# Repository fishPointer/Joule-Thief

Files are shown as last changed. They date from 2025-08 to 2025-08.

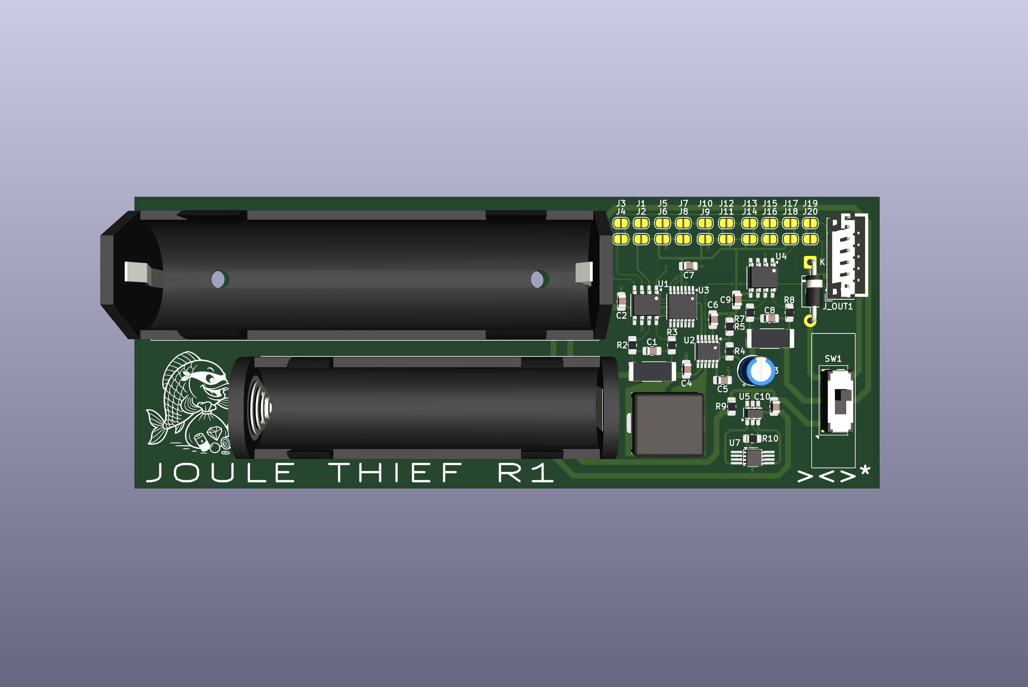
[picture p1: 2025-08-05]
KiCAD/Joule Thief/Renders/Joule Thief 3D Render.png

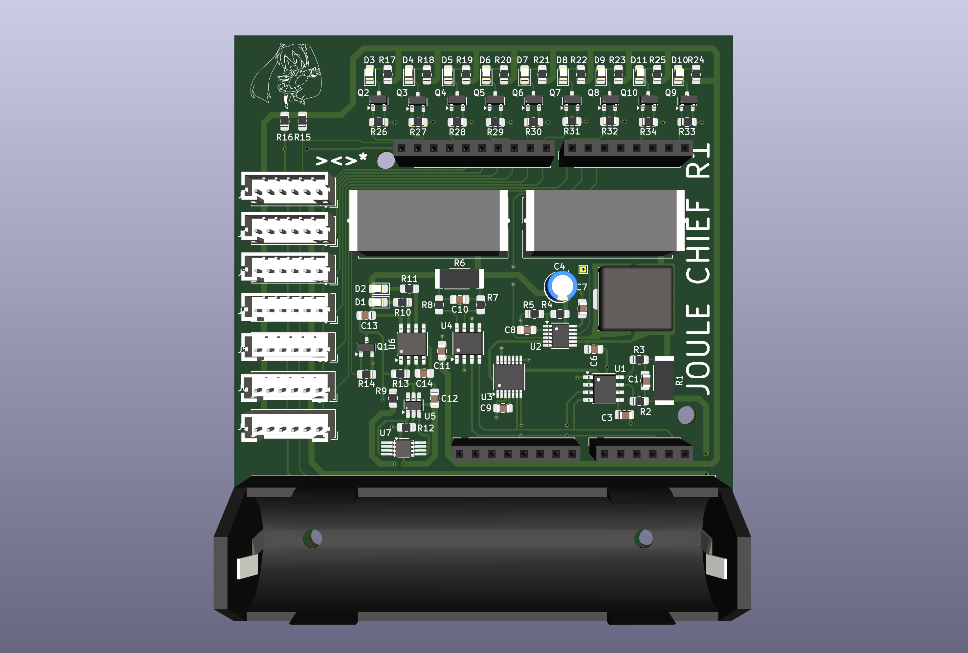
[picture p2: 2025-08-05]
KiCAD/Joule Chief/Renders/Joule Chief 3D Render.png

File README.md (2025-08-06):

Pasted image 20250805165937

# Joule Thief

## Overview
- **Purpose:** Exhibition project at Open Sauce July 18-20, 2025, Practice
- **Description:** High efficiency alkaline battery draining system with diagnostics and energy storage
- **Domain:** Precision energy harvesting & instrumentation

**Objectives:**
- Extract all usable electrical energy from used/"dead" Alkaline Cells (AA, AAA, etc.)
- Measure & Log energy extraction data from each cell & deliver analytics
- Efficiently convert and push energy extracted into a Li-Ion power bank

**Topology**
- **INA219** - Energy Metering
- **LTC3105** - Low Voltage Boost Converter
- **AD5280** - Digital Potentiometer, 200kΩ
- **DW01** - 18650 Single-cell BMS
- **TP4056** - Single-cell 18650 Charger
- **FS8205** - Dual-FET package for DW01
- **AO3400** - Low Voltage N-E-FET
- **1N5817** - Low Voltage Schottky Diode

**Status:** Complete. Exhibited. Working on Finalizing Documentation.

**Additional Documentation:** available on my Obsidian at [suneaterlabs.com](https://suneaterlabs.com).

**Why Joule Thief?**
This project was started as a New Year's Resolution to exhibit at Open Sauce 2025, and was finished 2 days prior to the event.
I have no commercial intent with this project. I don't believe that it is particularly novel, and a close look by anyone experienced with energy harvesting & power electronics should rightly reveal it as something akin to a useless machine.

I teach myself new skills by designing projects that require to develop the skills I want in order to complete them. I put a high level of effort into this project because I wanted to go through the process of designing a relatively performant embedded system without referencing anyone else's work. Just pick functionalities and features, set a spec, and then flip through datasheets until you find the right combination. Then put it all together and prove that it works. Design the schematic, route a board, write the firmware, etc. and then package it all up and provide thorough documentation on the whole thing.

I had never done any of that before and I have no professional experience working as an electronics engineer. I do have an EE degree and currently work in power system analysis for hyperscale datacenters, so this project is actually something like a microcosm of my day job. There is little overlap though, and I consider myself self-taught here. I learned a lot!

## System Description

### Joule Thief - Core Functionality
Joule Thief Schematic
The Joule Thief is designed to fully deplete alkaline cells of any remaining energy, long after they will fail to turn on their devices. The core of this design is the LTC3105, which can handle input voltages as low as 250mV. A quick look at an alkaline cell's SOC-OCV curve will show that draining to 300mV is sufficient to say >99% of total energy has been drained.

The classic Joule Thief is a simple party trick involving a dead battery, a hand-wound toroid, and a BJT. It is essentially using the voltage spike from inductive kickback to PWM an LED back to life. My motivation for this project was to demonstrate that there is a considerable amount of energy left in alkaline cells when they are discarded, so I set out to build an overengineered energy harvester that could precisely quantify how much energy was actually left in a dead cell, and then store it into a lithium-based battery bank to further prove the point.

 In order to improve performance and maximize both energy throughput and conversion efficiency, there is an INA219 shunt meter on either side of the LTC3105 boost chip allowing for efficiency tracking during processing & live diagnostics. 
 Additionally, the LTC3105 includes an MPPC pin, which enables a variable resistance to throttle the inductor's switching in order to achieve a specified input voltage. With the addition of an AD5280-200kΩ digital potentiometer attached to the MPPC pin, it is possible to read in energy measurements from the INA219's into a microcontroller, and then adjust the setting of the LTC3105 accordingly. The result is a control loop that can maximize the energy extraction rate regardless of the target cell's health or state of charge. 
 
 This INA219+LTC3105+AD5280 system can be tuned for maximum efficiency or maximum average power extracted, but optimizing for energy throughput has far greater performance gains. Using a DC Electronic Load to produce a slow sweep of load resistance values across a fresh AA alkaline cell will result in no more than 400-500mW peak extraction rate, and chemical effects such as electrolyte gradient formation and ion depletion make this power output unstable and liable to rapidly decline. The dynamic approach explored in the Joule Thief is able to achieve 900-1100mW peak output power, and can reliably maintain 600-700mW extraction rate in the early life of a cell. Additionally, the MPPC schema prevents the cell's output capacity from being overwhelmed by the battery chemistry effects, and the cell will continuously output higher power than traditional Joule Thief circuits or static loads.

The Joule Thief Extraction Module is also designed to run in "headless" mode without an MCU. No diagnostics are available in this mode (obviously) and the board will be able to move the energy from a single AA cell into a single 18650 cell safely.

### Joule Chief - Core Functionality
Joule Chief Schematic
The Joule Chief was designed to be a mainboard that allows for the consolidation of harvested energy from an arbitrary number of Joule Thief Extraction Modules collecting energy from different sources at different rates. The Joule Chief serves as both an aggregator and an abstraction layer for the energy harvested. 

The Joule Chief begins with a low-voltage schottky diode on the output of the extraction module to prevent backflow. After the energy is delivered to the mainboard's input bus, all the energy is stored in a 1F supercapacitor. The Joule Thief Extraction Modules are all set to boost whatever energy source they are targeting to 5V and charge the 1F supercap to 5V accordingly. 

Readings from the mainboard's INA219 allow the MCU to precisely track the voltage of the supercap as well as the power flowing into this buffer. The MCU is programmed to operate a schmitt trigger with thresholds at 2.5V and 5V, only enabling the 1F supercap's energy to pass through the mainboard's LTC3105 after 5V has been reached, and until 2.5V. This region of input voltage allows the boost chip to operate in a high-efficiency mode.

Once the energy has moved through the 1F supercap and through the LTC3105, it is stored in a second 1F supercap connected to the lithium cell charger. The cell charger is controlled by a second schmitt trigger running on the MCU as well. This schmitt trigger keeps the second 1F energy buffer between 4.5V and 5.0V, such that the buffer will always be an appropriate voltage for charging a lithium cell (3.0V to 4.3V).

The Joule Chief can handle an arbitrary number of extraction modules each working on arbitrarily weak or intermittent energy sources. This mainboard can effectively accumulate these energy sources and efficiently deposit this energy via intermittent pulses of energy into a rechargeable battery bank for later use while providing precise diagnostics at every stage of the harvesting process. The frequency of these charging pulses is dependent on the strength of the sources. Harvesting a sufficiently powerful source, such as a fresh AA cell, will allow the mainboard to achieve steady-state operation, and a continuous current flow into the 18650 becomes possible.

Both the Joule Thief and Joule Chief boards currently use a generic and inefficient BMS stack consisting of a DW01 for OC/OCD/SC protection, an FS8205 dual-FET package for breaking the circuit, and a TP4056 charging IC. This BMS is largely unnecessary given the low-power nature of this application, but was included for safety and peace of mind.

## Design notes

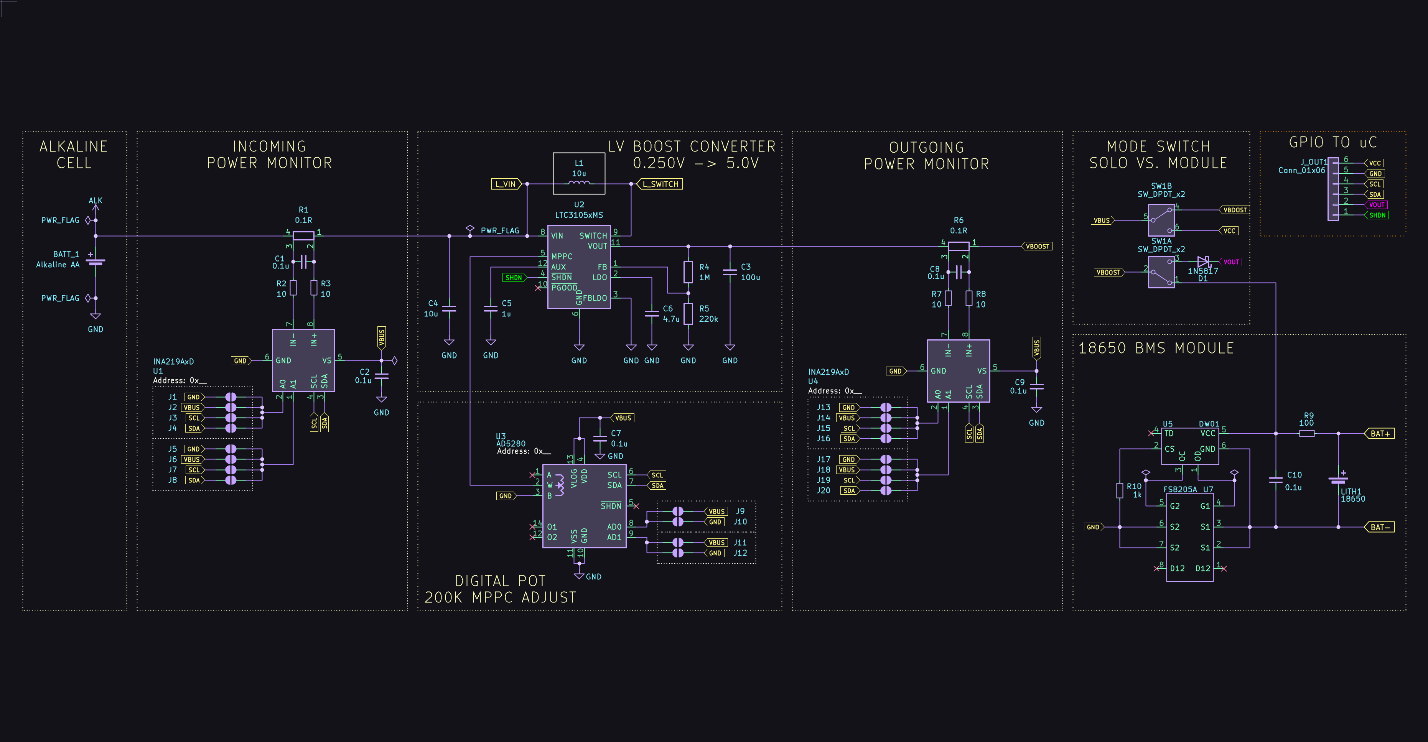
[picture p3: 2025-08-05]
KiCAD/Joule Thief/Renders/Joule Thief Schematic.png

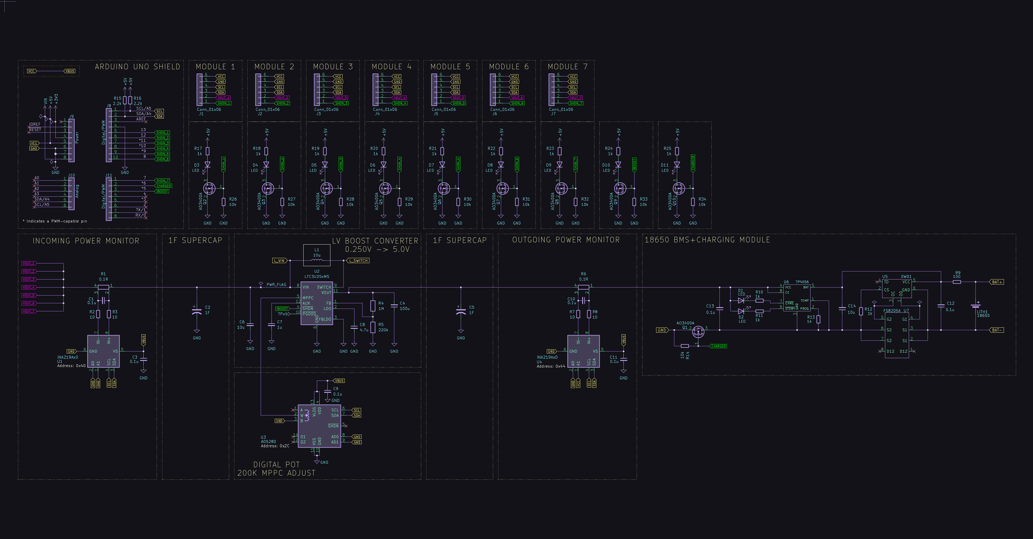
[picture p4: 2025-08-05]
KiCAD/Joule Chief/Renders/Joule Chief Schematic.png

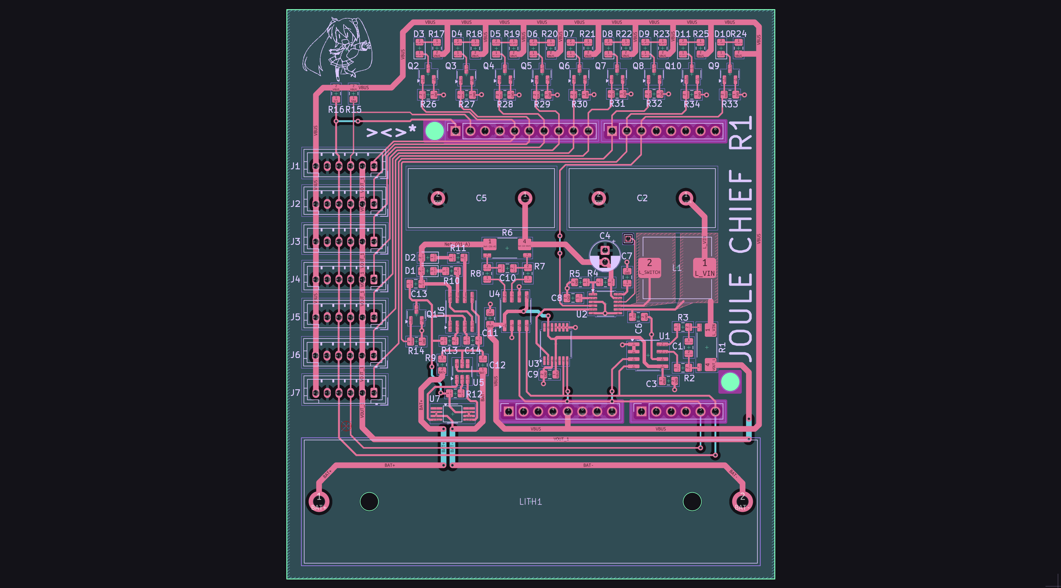
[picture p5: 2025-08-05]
KiCAD/Joule Chief/Renders/Joule Chief Layout.png

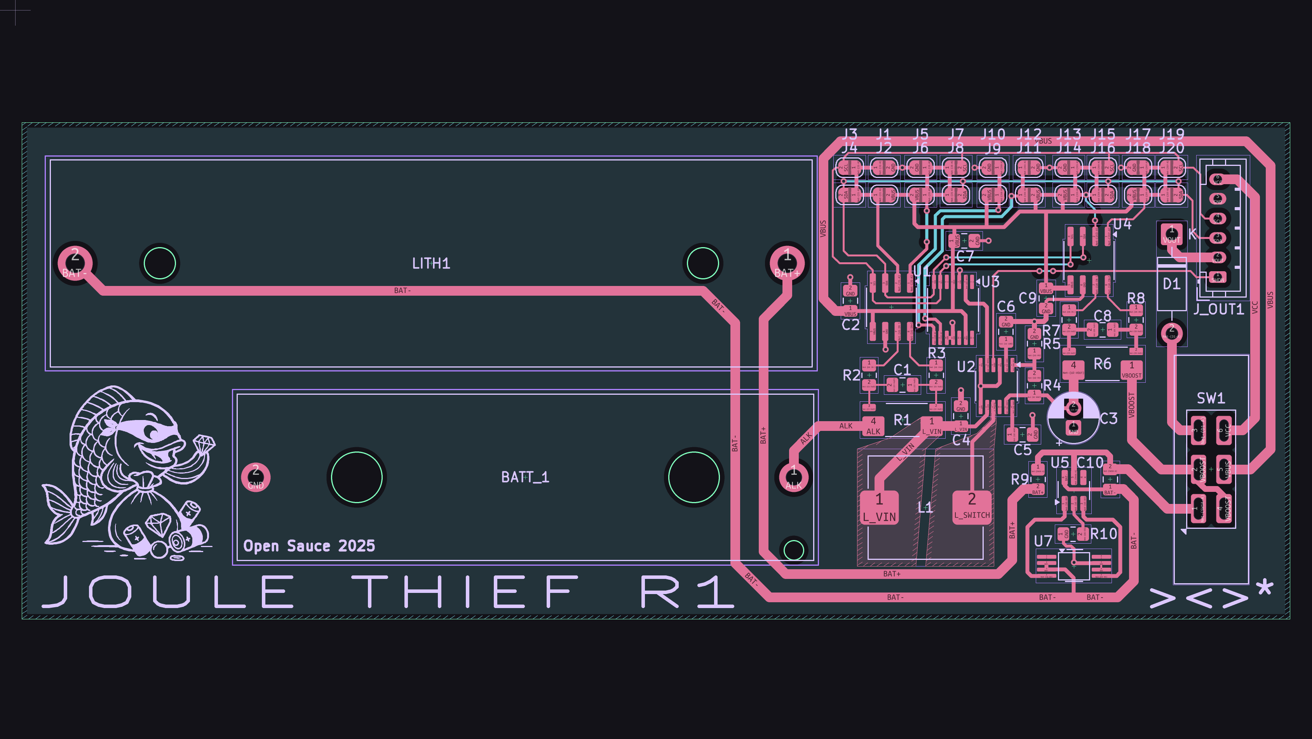
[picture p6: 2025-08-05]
KiCAD/Joule Thief/Renders/Joule Thief Layout.png

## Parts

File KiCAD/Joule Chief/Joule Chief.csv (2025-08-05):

Reference | Value | Qty | Footprint
C1,C3,C9,C10,C11,C12,C13 | 0.1u | 7 | Capacitor_SMD:C_0805_2012Metric_Pad1.18x1.45mm_HandSolder
C2,C5 | 1F | 2 | Joule Thief Footprints:1F_Supercap
C4 | 100u | 1 | Capacitor_THT:CP_Radial_D5.0mm_P2.00mm
C6,C14 | 10u | 2 | Capacitor_SMD:C_0805_2012Metric_Pad1.18x1.45mm_HandSolder
C7 | 1u | 1 | Capacitor_SMD:C_0805_2012Metric_Pad1.18x1.45mm_HandSolder
C8 | 4.7u | 1 | Capacitor_SMD:C_0805_2012Metric_Pad1.18x1.45mm_HandSolder
D1,D2,D3,D4,D5,D6,D7,D8,D9,D10,D11 | LED | 11 | LED_SMD:LED_0805_2012Metric_Pad1.15x1.40mm_HandSolder
J1,J2,J3,J4,J5,J6,J7 | Conn_01x06 | 7 | Connector_JST:JST_PH_B6B-PH-K_1x06_P2.00mm_Vertical
J8,J11 | Digital/PWM | 2 | Connector_PinSocket_2.54mm:PinSocket_1x08_P2.54mm_Vertical,Connector_PinSocket_2.54mm:PinSocket_1x10_P2.54mm_Vertical
J9 | Power | 1 | Connector_PinSocket_2.54mm:PinSocket_1x08_P2.54mm_Vertical
J10 | Analog | 1 | Connector_PinSocket_2.54mm:PinSocket_1x06_P2.54mm_Vertical
L1 | 10u | 1 | Joule Thief Footprints:Power_Inductor_101040
LITH1 | 18650 | 1 | Joule Thief Footprints:18650_Cell_Clip_V2
Q1,Q2,Q3,Q4,Q5,Q6,Q7,Q8,Q9,Q10 | AO3400A | 10 | Package_TO_SOT_SMD:SOT-23
R1,R6 | 0.1R | 2 | Joule Thief Footprints:R_Shunt_2512_V2
R2,R3,R7,R8 | 10 | 4 | Resistor_SMD:R_0805_2012Metric_Pad1.20x1.40mm_HandSolder
R4 | 1M | 1 | Resistor_SMD:R_0805_2012Metric_Pad1.20x1.40mm_HandSolder
R5 | 220k | 1 | Resistor_SMD:R_0805_2012Metric_Pad1.20x1.40mm_HandSolder
R9 | 100 | 1 | Resistor_SMD:R_0805_2012Metric_Pad1.20x1.40mm_HandSolder
R10,R11,R12,R13,R17,R18,R19,R20,R21,R22,R23,R24,R25 | 1k | 13 | Resistor_SMD:R_0805_2012Metric_Pad1.20x1.40mm_HandSolder
R14,R26,R27,R28,R29,R30,R31,R32,R33,R34 | 10k | 10 | Resistor_SMD:R_0805_2012Metric_Pad1.20x1.40mm_HandSolder
R15,R16 | 2.2k | 2 | Resistor_SMD:R_0805_2012Metric_Pad1.20x1.40mm_HandSolder
TPx1 | TestPoint_Alt | 1 | TestPoint:TestPoint_THTPad_1.0x1.0mm_Drill0.5mm
U1,U4 | INA219AxD | 2 | Package_SO:SOIC-8_3.9x4.9mm_P1.27mm
U2 | LTC3105xMS | 1 | Package_SO:MSOP-12_3x4.039mm_P0.65mm
U3 | AD5280 | 1 | Package_SO:TSSOP-14_4.4x5mm_P0.65mm
U5 | DW01 | 1 | Package_TO_SOT_SMD:SOT-23-6_Handsoldering
U6 | TP4056 | 1 | Package_SO:SOIC-8-1EP_3.9x4.9mm_P1.27mm_EP2.29x3mm
U7 | FS8205A | 1 | Joule Thief Footprints:FS8205A_Wide

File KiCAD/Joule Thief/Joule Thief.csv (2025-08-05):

Reference | Value | Qty | Footprint
BATT_1 | Alkaline AA | 1 | Joule Thief Footprints:AA_Cell_Clip_V2
C1,C2,C7,C8,C9,C10 | 0.1u | 6 | Capacitor_SMD:C_0805_2012Metric_Pad1.18x1.45mm_HandSolder
C3 | 100u | 1 | Capacitor_THT:CP_Radial_D5.0mm_P2.00mm
C4 | 10u | 1 | Capacitor_SMD:C_0805_2012Metric_Pad1.18x1.45mm_HandSolder
C5 | 1u | 1 | Capacitor_SMD:C_0805_2012Metric_Pad1.18x1.45mm_HandSolder
C6 | 4.7u | 1 | Capacitor_SMD:C_0805_2012Metric_Pad1.18x1.45mm_HandSolder
D1 | 1N5817 | 1 | Diode_THT:D_DO-41_SOD81_P10.16mm_Horizontal
J_OUT1 | Conn_01x06 | 1 | Connector_JST:JST_PH_B6B-PH-K_1x06_P2.00mm_Vertical
L1 | 10u | 1 | Joule Thief Footprints:Power_Inductor_101040
LITH1 | 18650 | 1 | Joule Thief Footprints:18650_Cell_Clip_V2
R1,R6 | 0.1R | 2 | Joule Thief Footprints:R_Shunt_2512_V2
R2,R3,R7,R8 | 10 | 4 | Resistor_SMD:R_0805_2012Metric_Pad1.20x1.40mm_HandSolder
R4 | 1M | 1 | Resistor_SMD:R_0805_2012Metric_Pad1.20x1.40mm_HandSolder
R5 | 220k | 1 | Resistor_SMD:R_0805_2012Metric_Pad1.20x1.40mm_HandSolder
R9 | 100 | 1 | Resistor_SMD:R_0805_2012Metric_Pad1.20x1.40mm_HandSolder
R10 | 1k | 1 | Resistor_SMD:R_0805_2012Metric_Pad1.20x1.40mm_HandSolder
SW1 | SW_DPDT_x2 | 1 | Joule Thief Footprints:SS22F25_DPDT_Straight_V2
U1,U4 | INA219AxD | 2 | Package_SO:SOIC-8_3.9x4.9mm_P1.27mm
U2 | LTC3105xMS | 1 | Package_SO:MSOP-12_3x4.039mm_P0.65mm
U3 | AD5280 | 1 | Package_SO:TSSOP-14_4.4x5mm_P0.65mm
U5 | DW01 | 1 | Package_TO_SOT_SMD:SOT-23-6_Handsoldering
U7 | FS8205A | 1 | Joule Thief Footprints:FS8205A_Wide

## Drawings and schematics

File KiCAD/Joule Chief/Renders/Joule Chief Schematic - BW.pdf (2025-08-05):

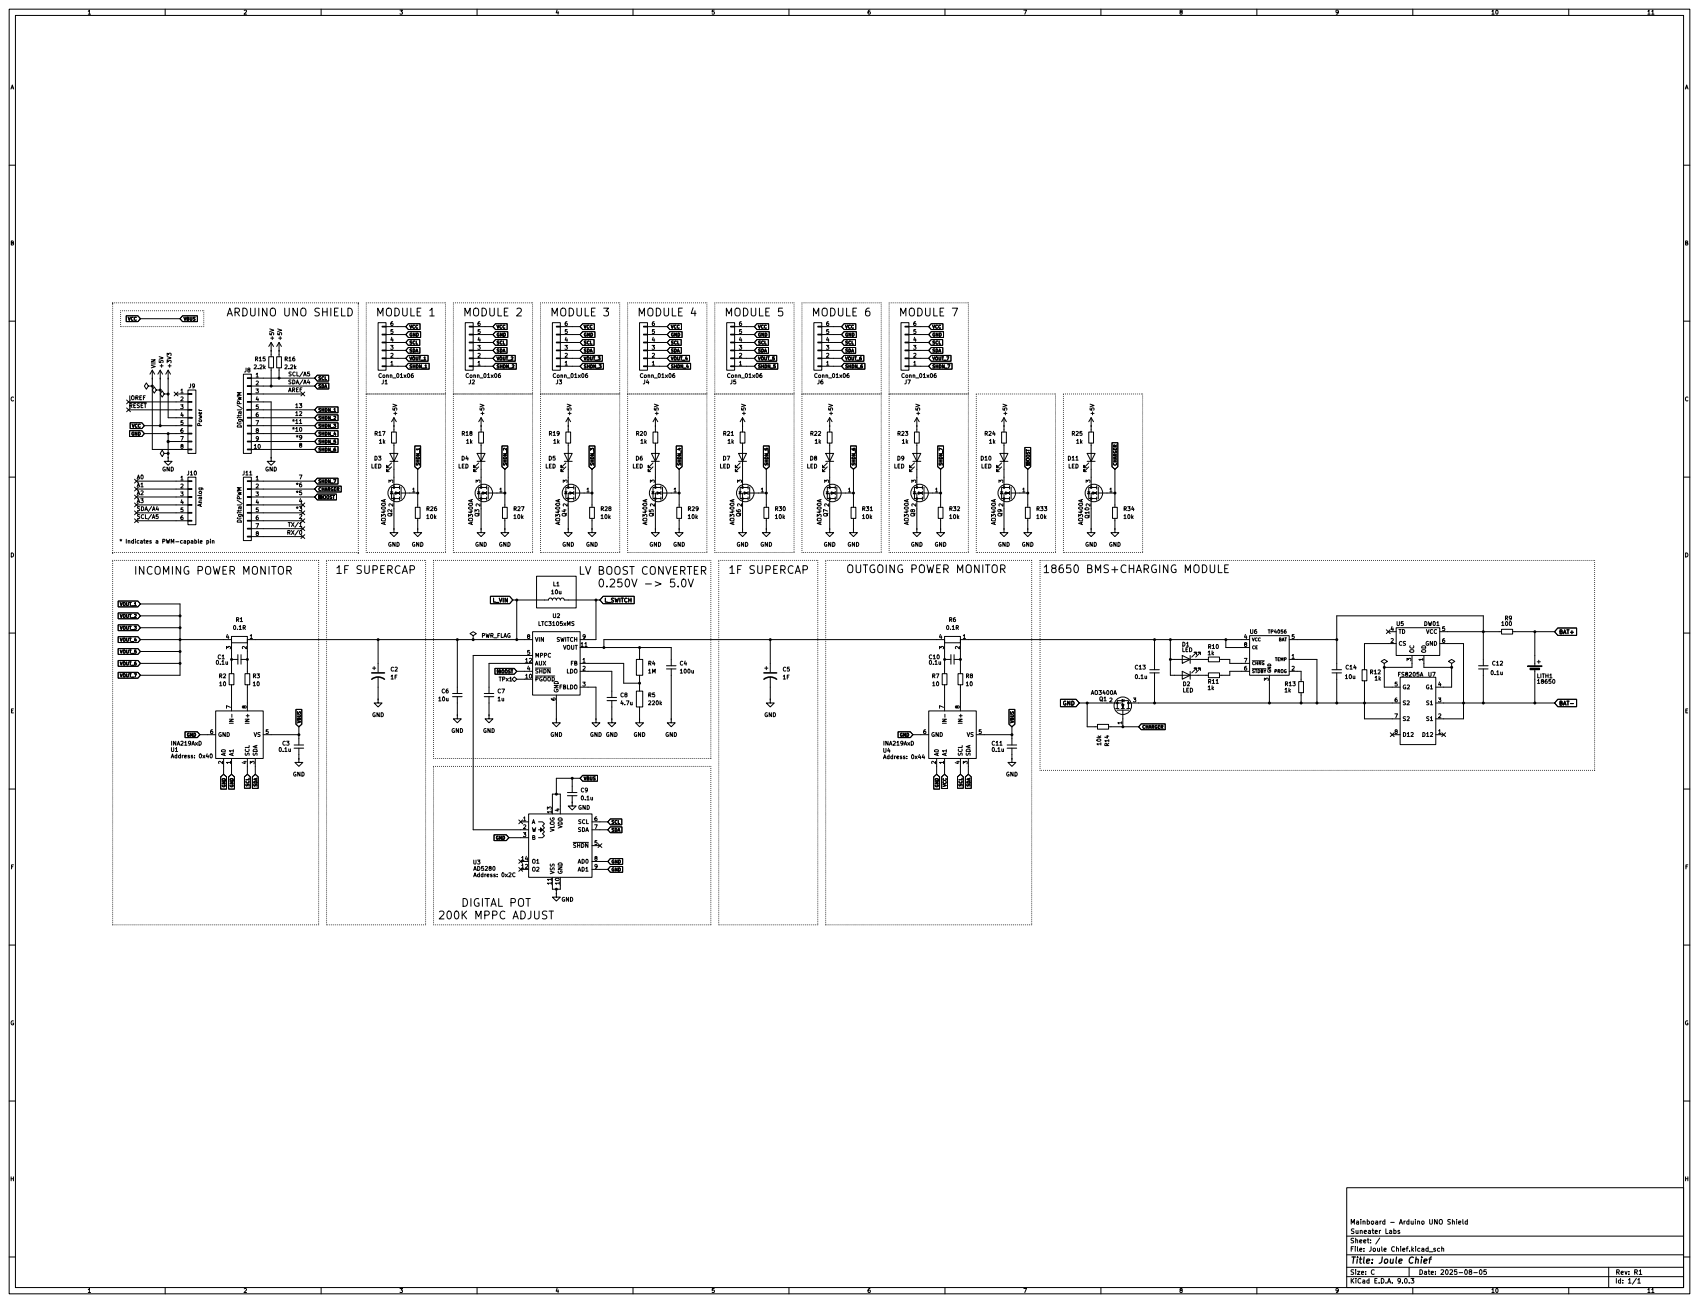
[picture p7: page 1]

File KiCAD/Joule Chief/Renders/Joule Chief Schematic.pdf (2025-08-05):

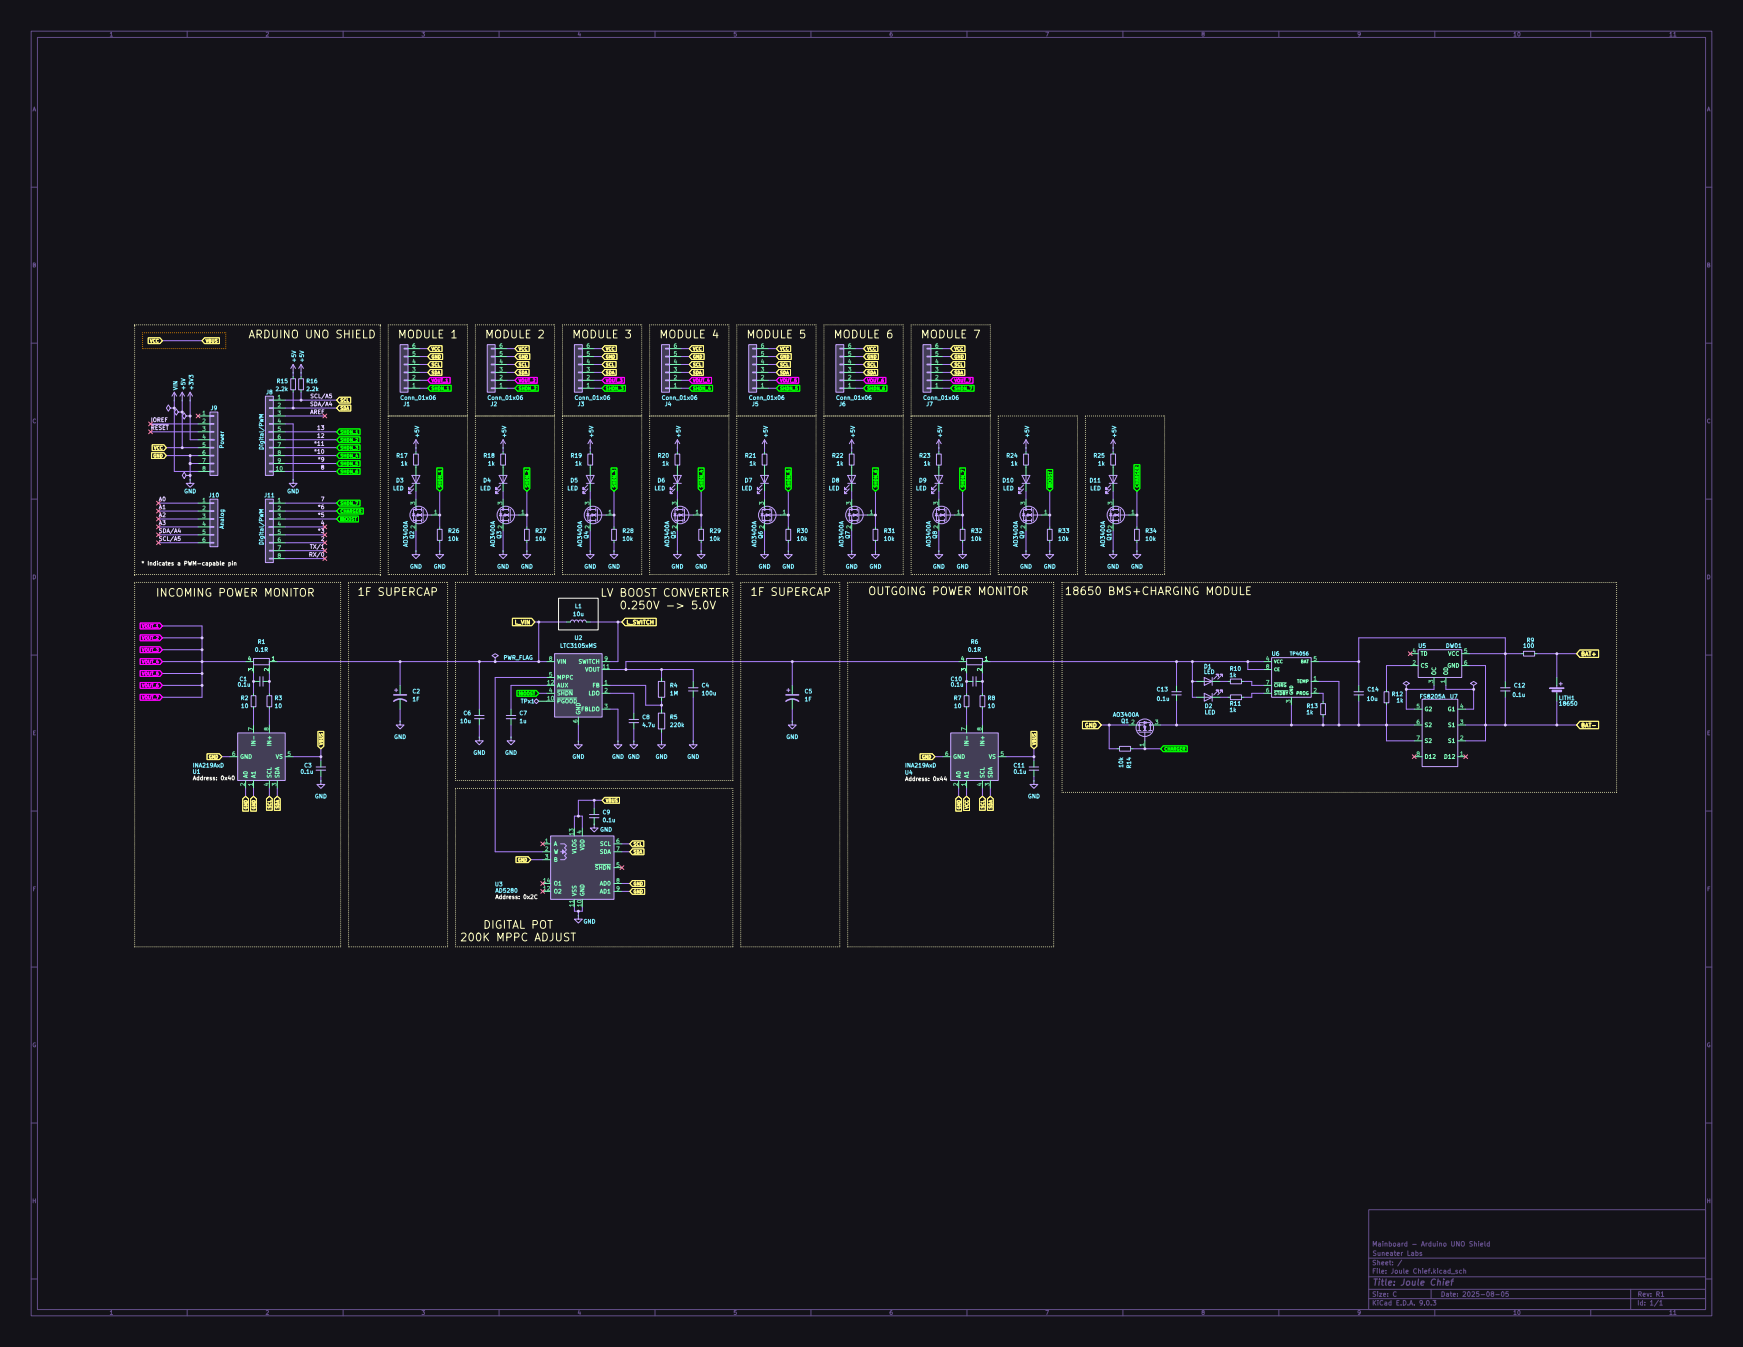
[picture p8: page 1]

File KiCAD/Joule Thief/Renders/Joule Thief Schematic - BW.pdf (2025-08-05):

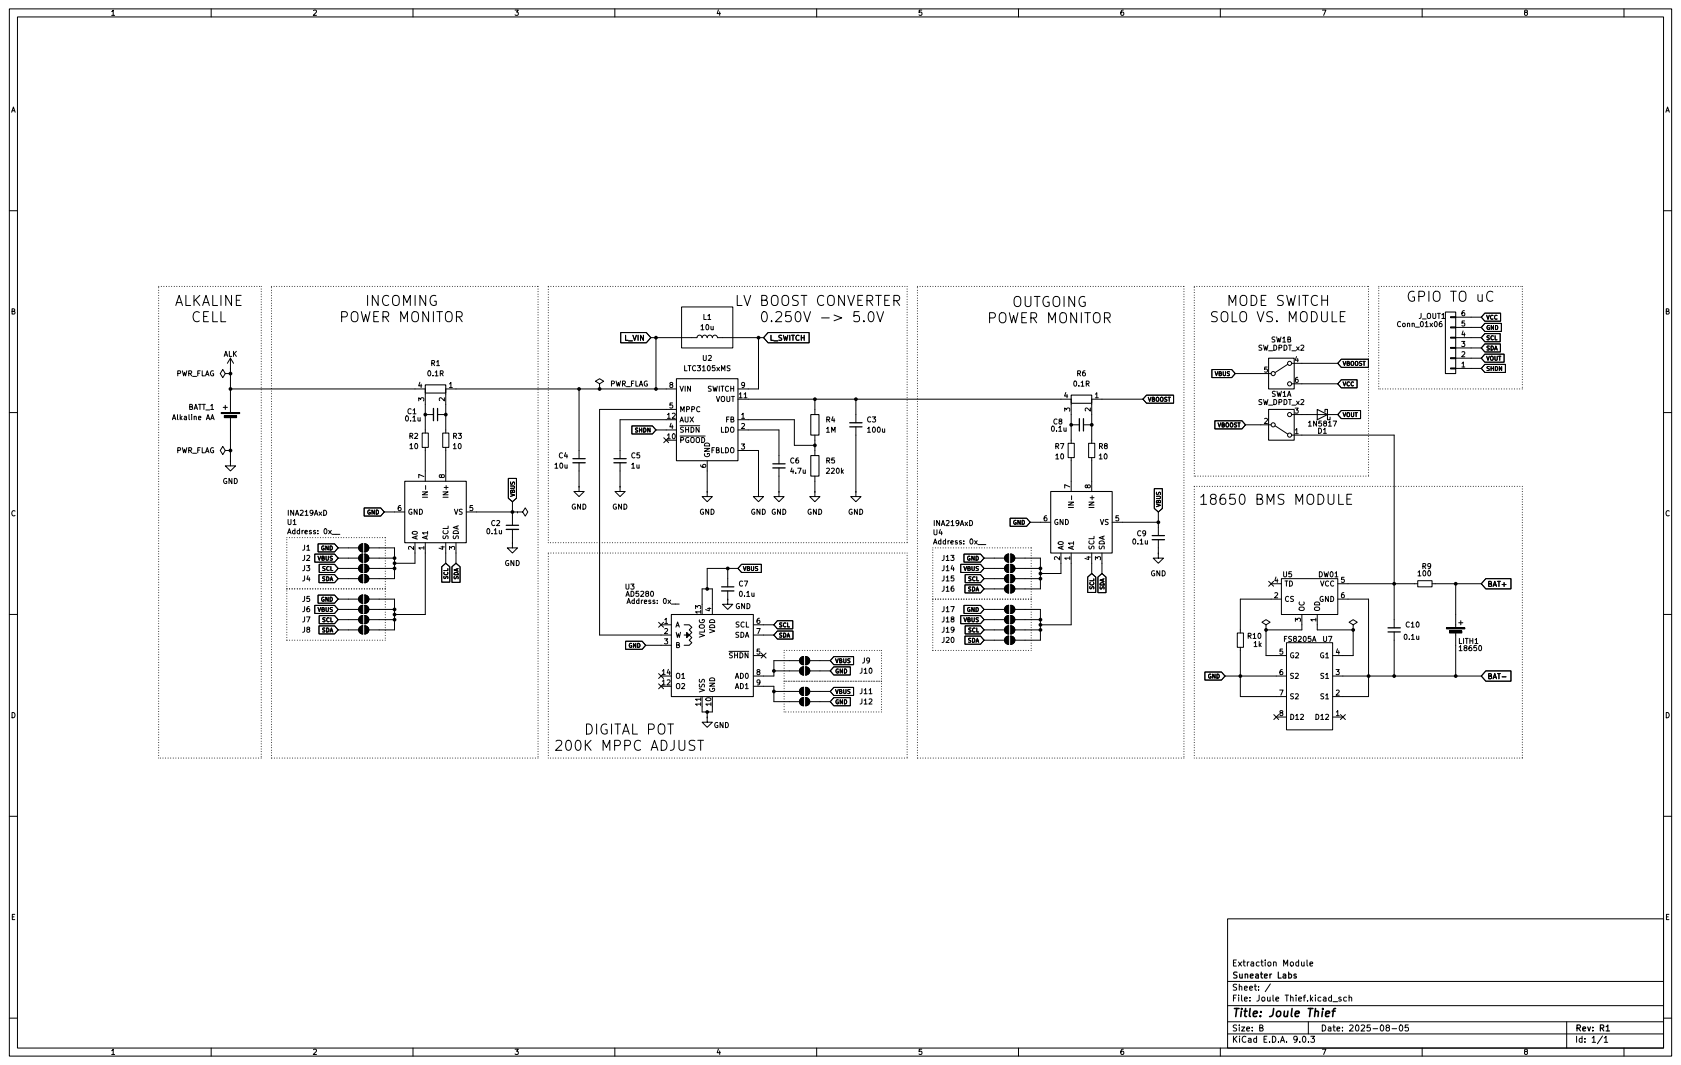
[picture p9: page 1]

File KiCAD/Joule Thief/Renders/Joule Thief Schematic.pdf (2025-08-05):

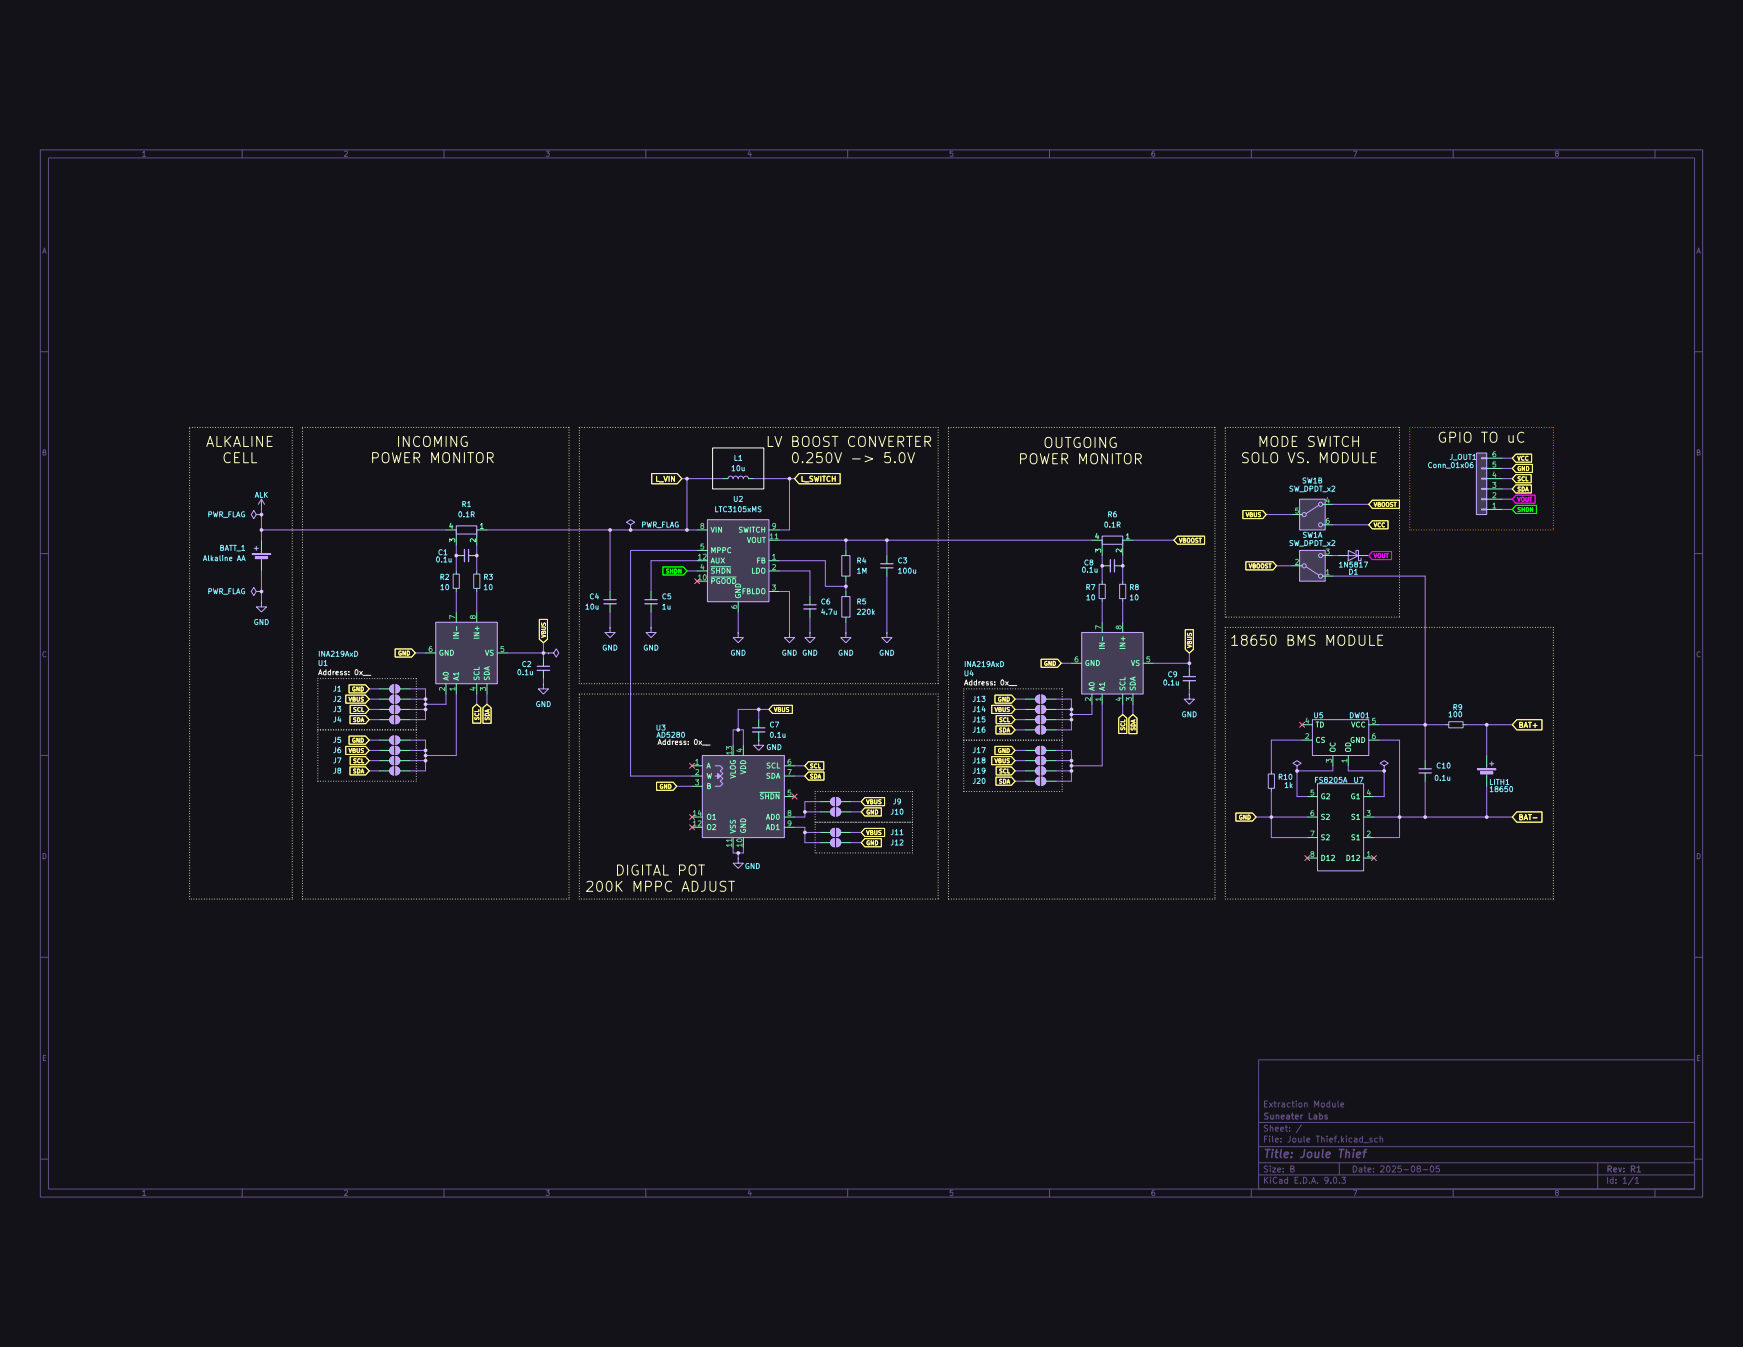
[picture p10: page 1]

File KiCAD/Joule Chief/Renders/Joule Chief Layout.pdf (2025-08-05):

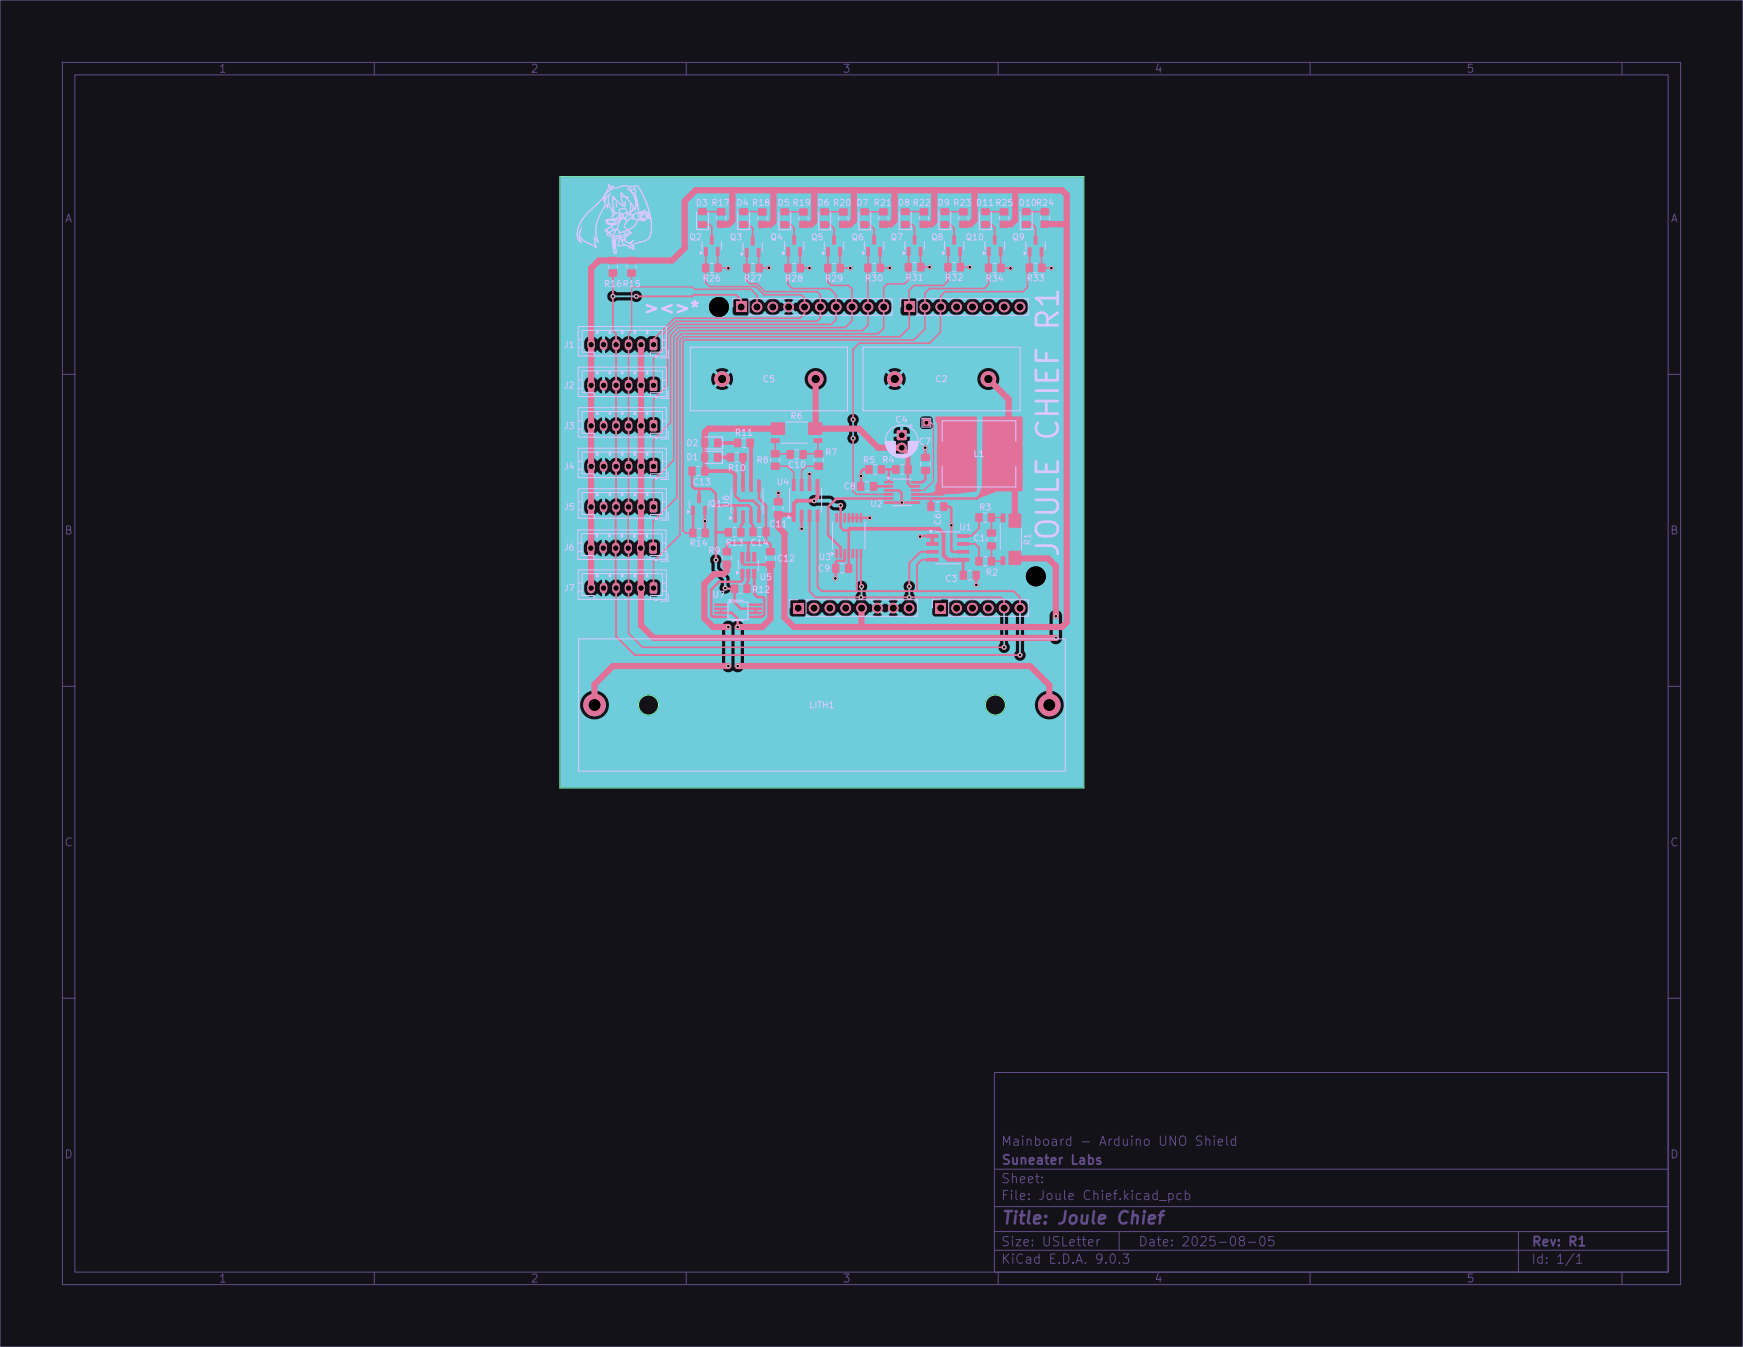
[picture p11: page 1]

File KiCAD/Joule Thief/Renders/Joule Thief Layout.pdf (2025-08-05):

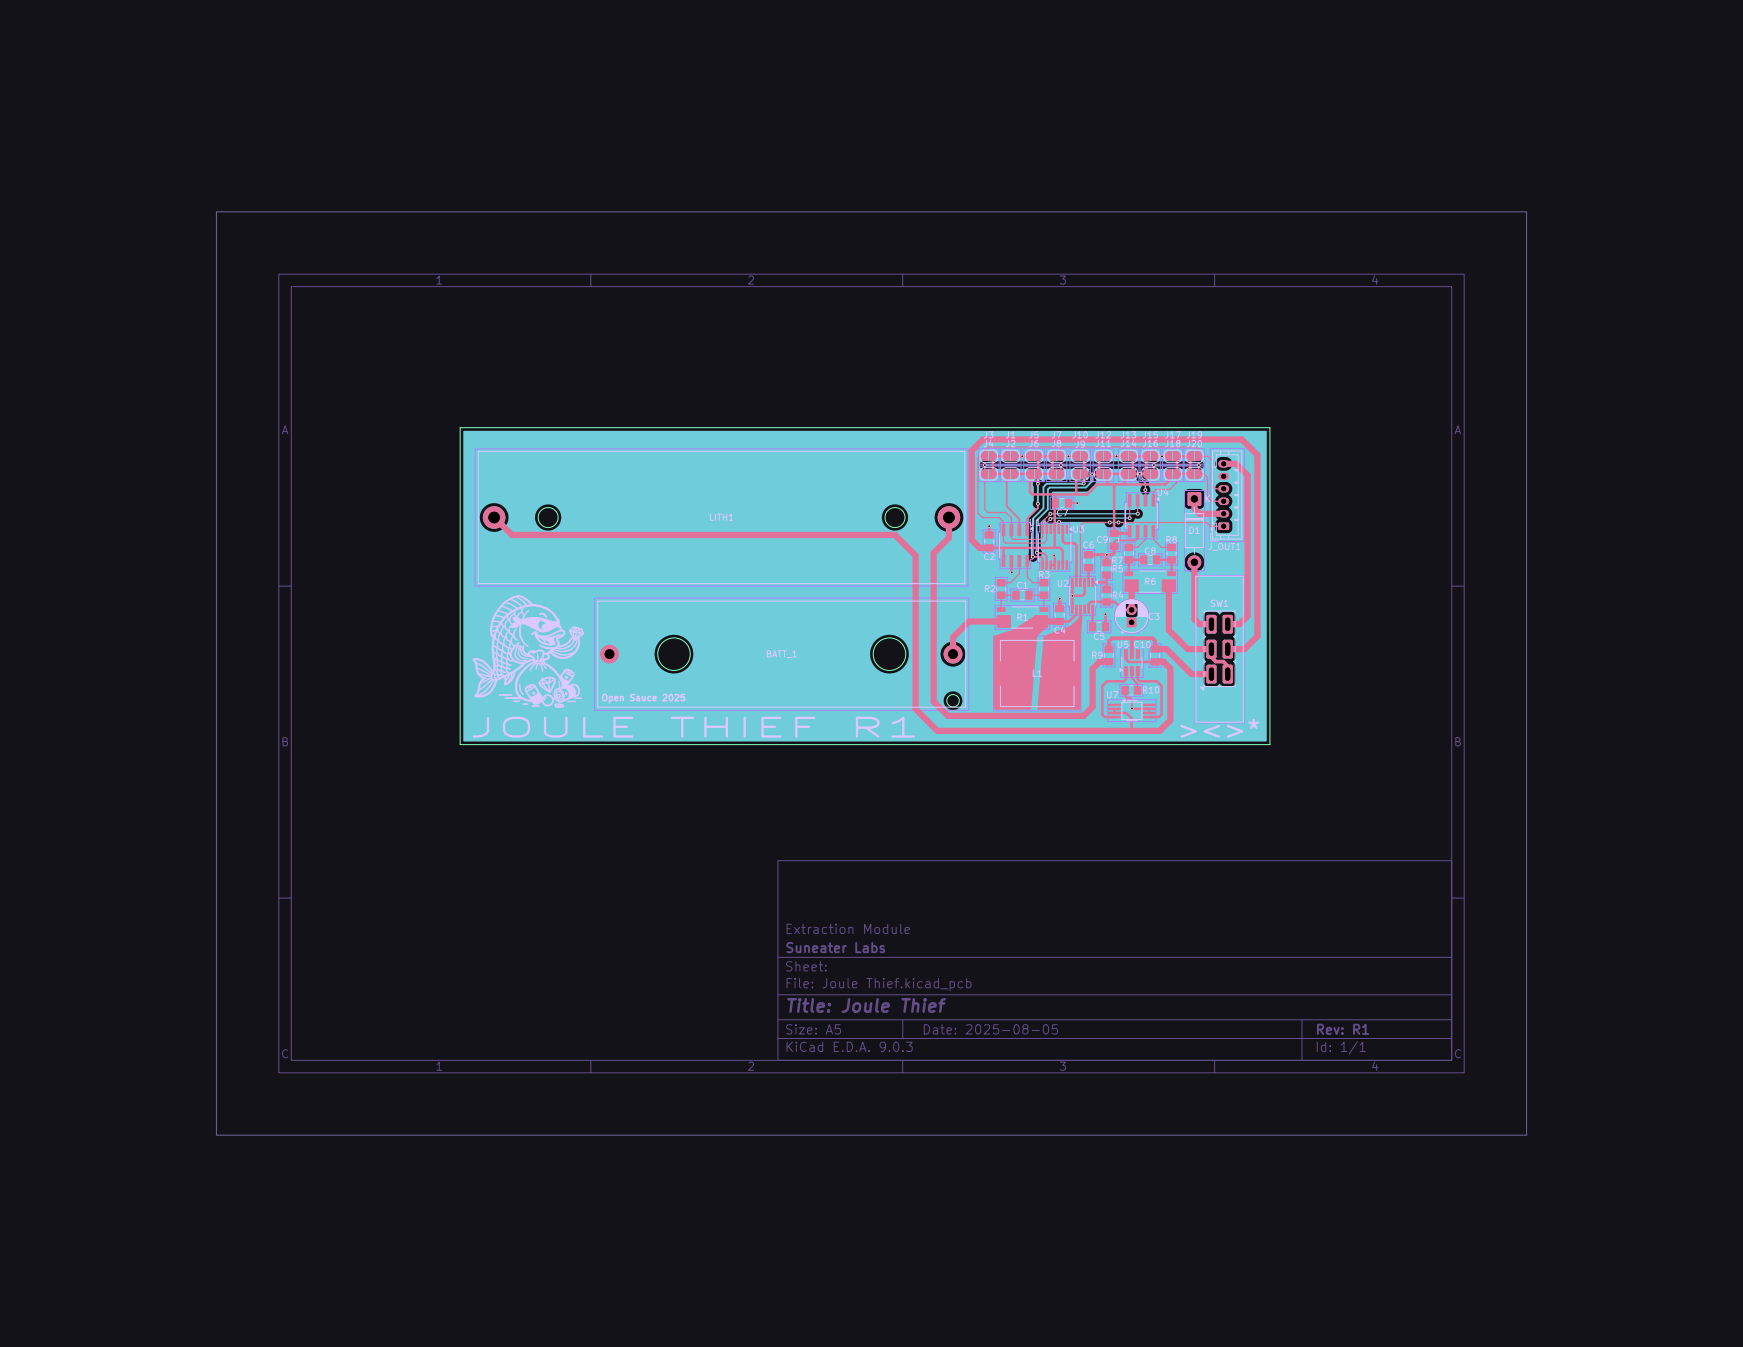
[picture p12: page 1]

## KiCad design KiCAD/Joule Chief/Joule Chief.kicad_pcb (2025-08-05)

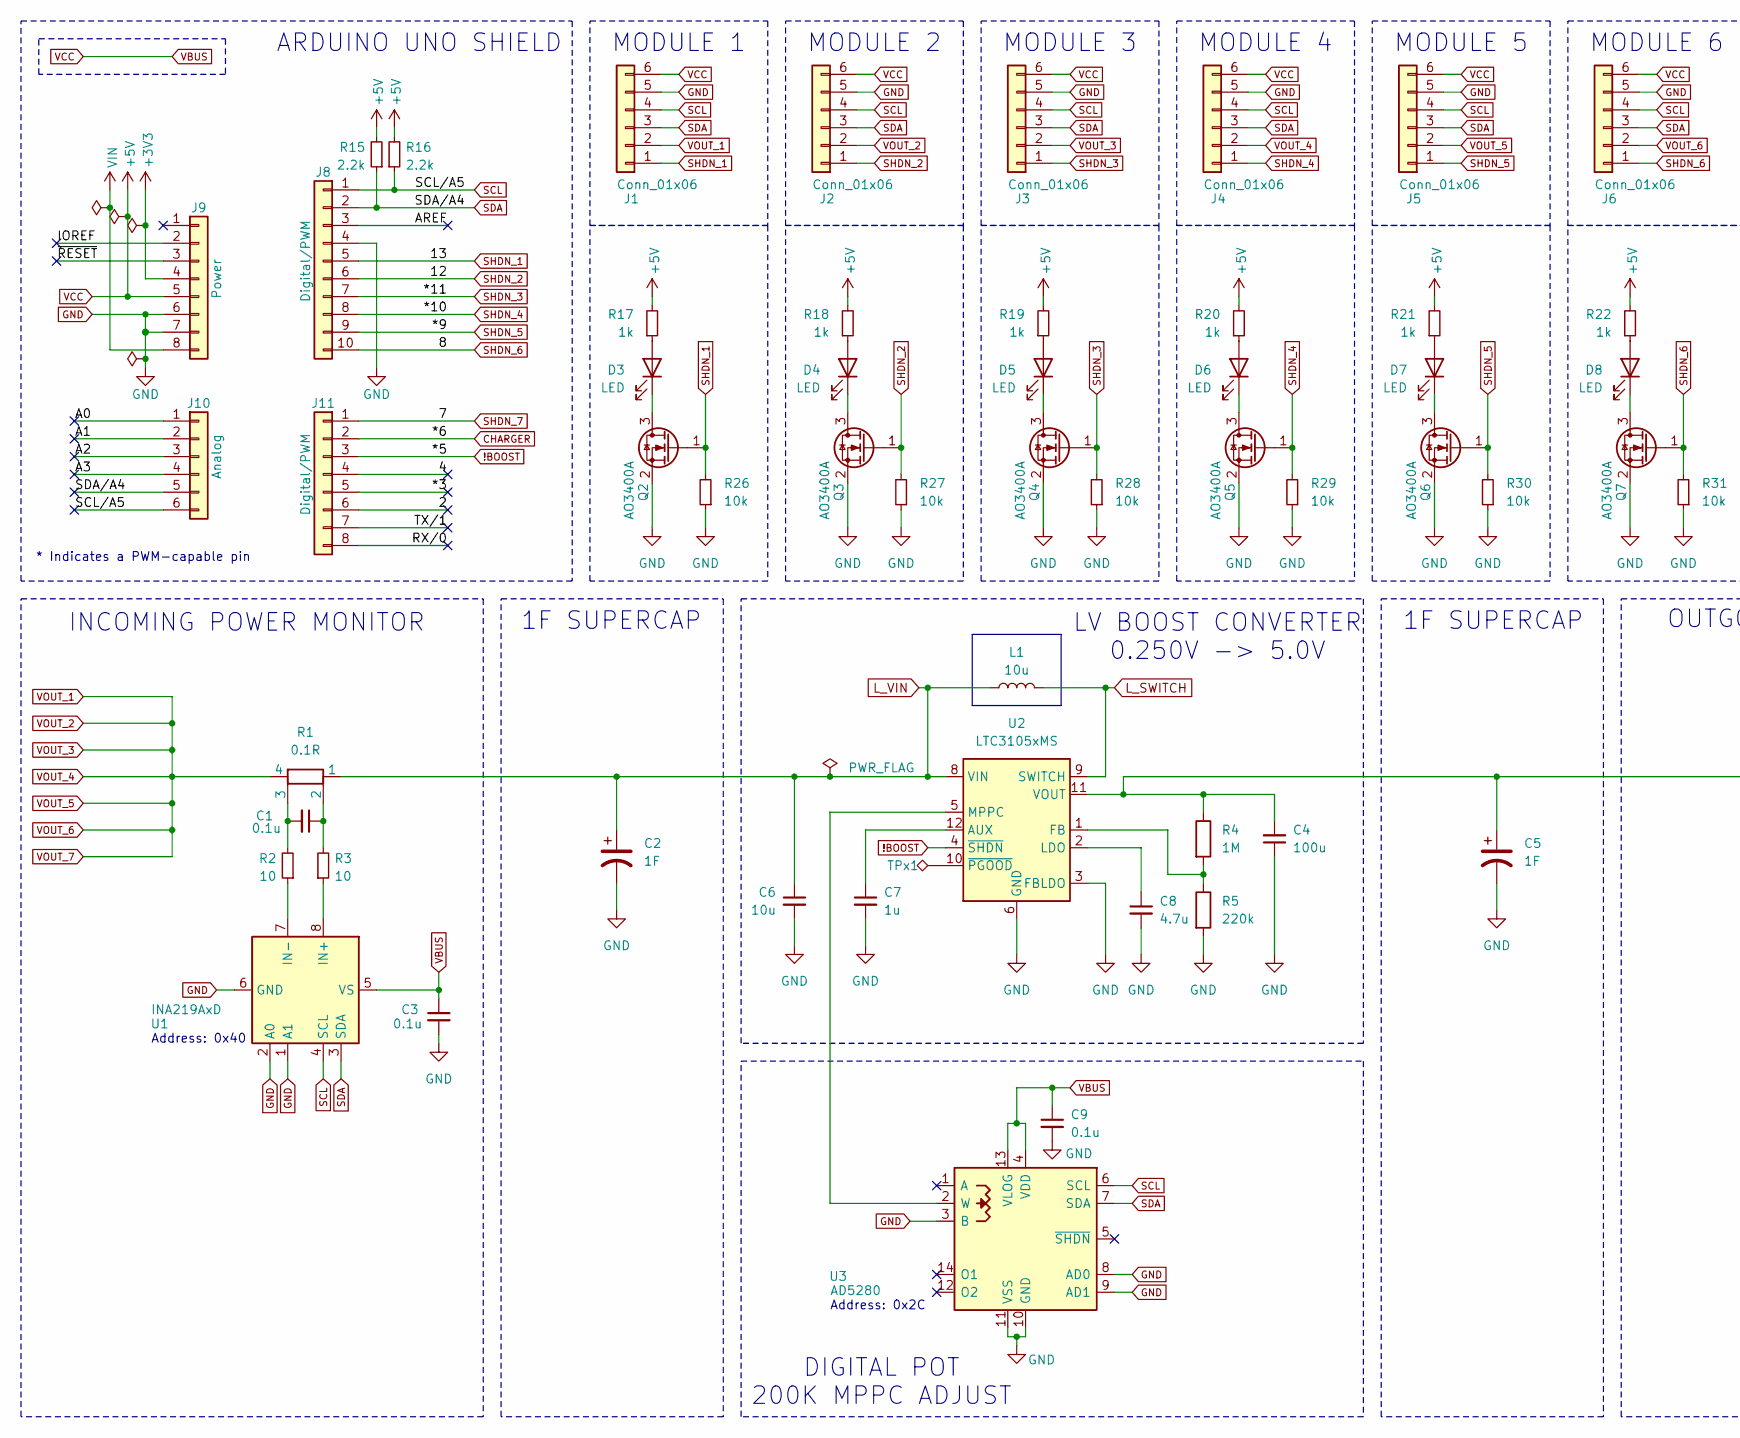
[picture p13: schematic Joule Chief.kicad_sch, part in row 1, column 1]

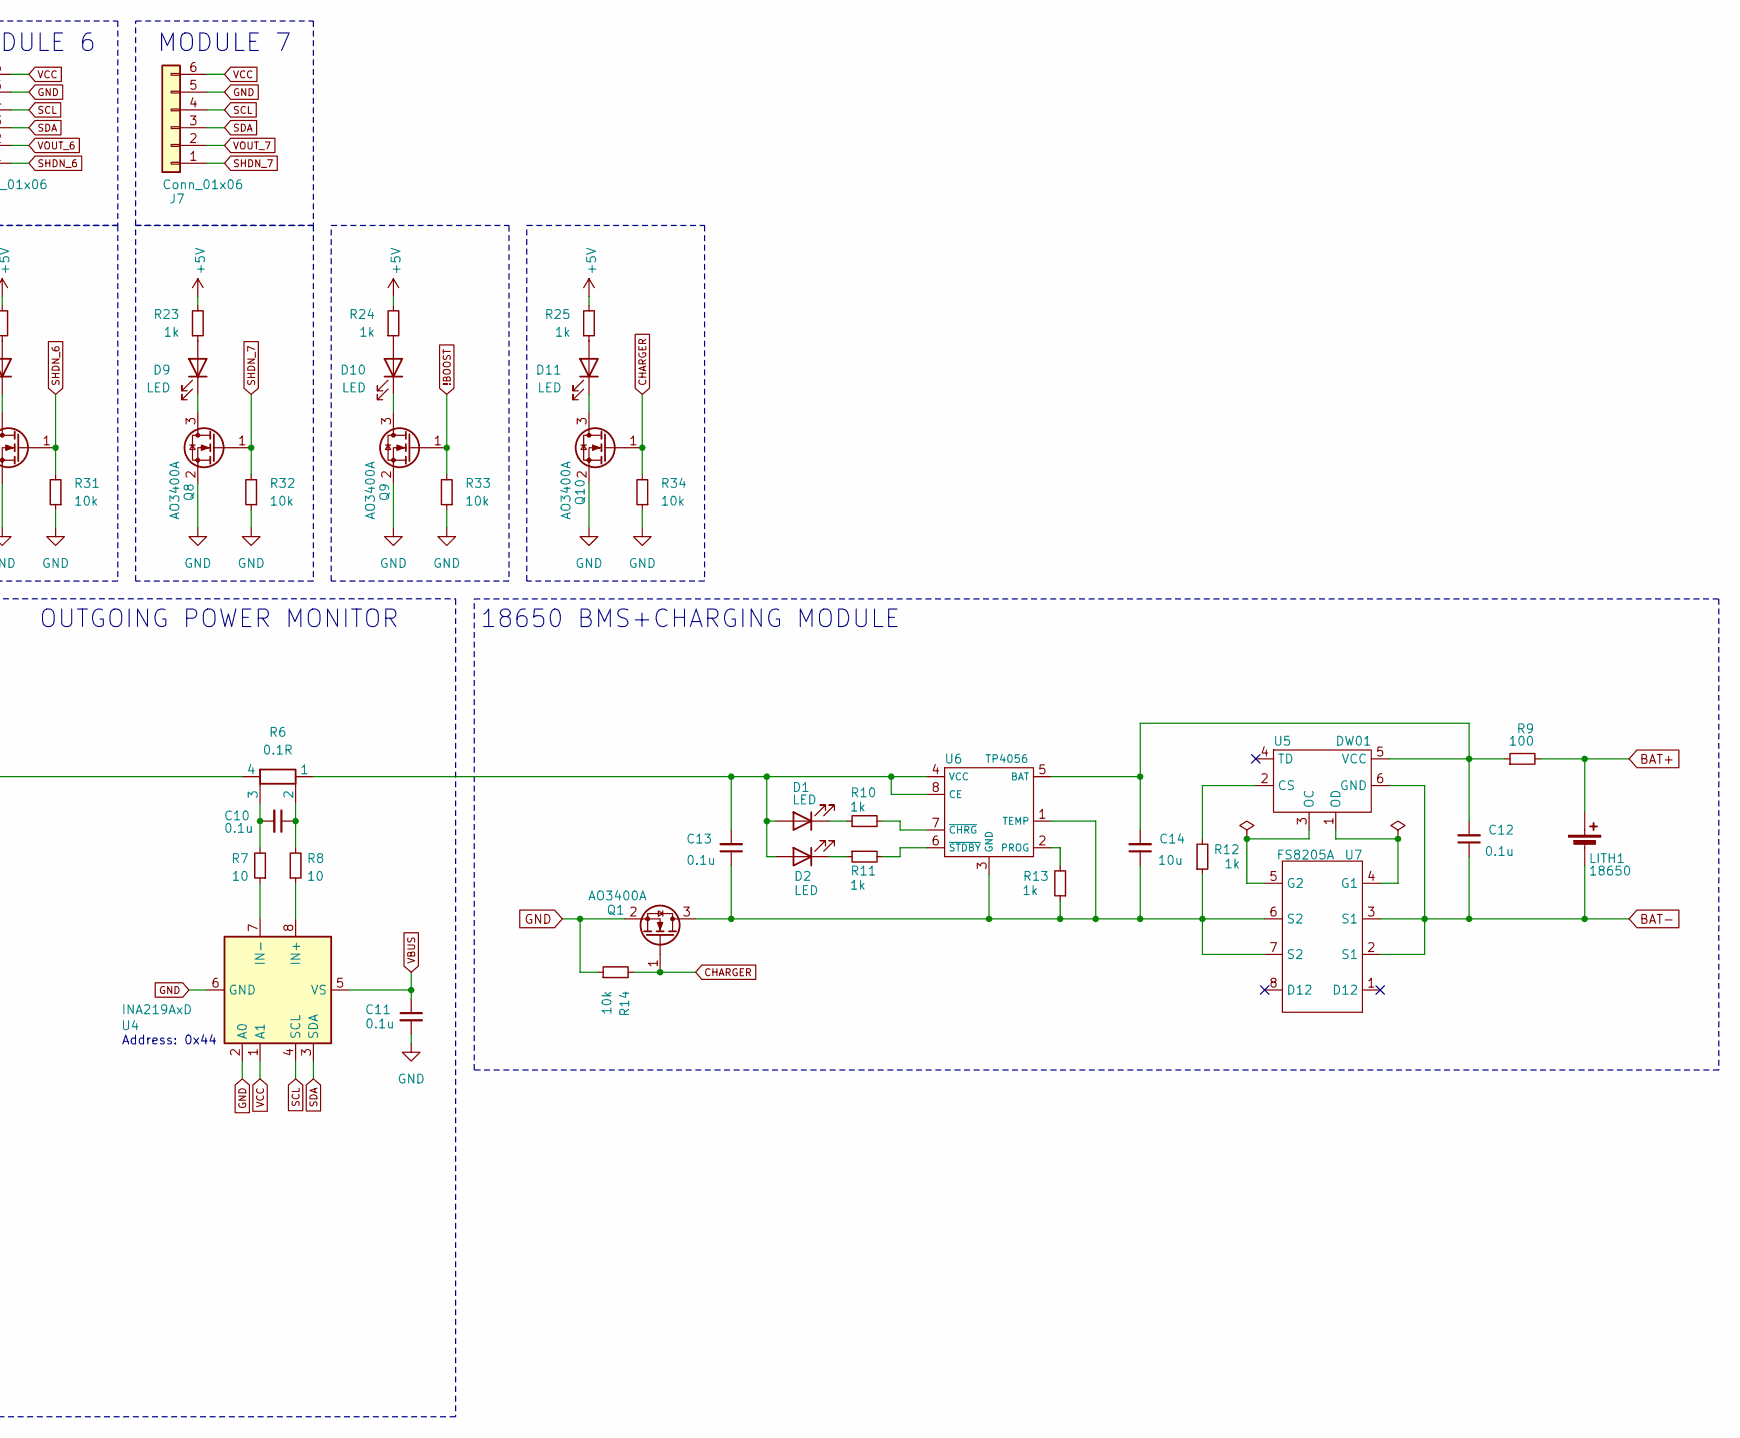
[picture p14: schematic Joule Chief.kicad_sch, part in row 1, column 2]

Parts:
C1, C3, C9, C10, C11, C12, C13: 0.1u; C_0805_2012Metric_Pad1.18x1.45mm_HandSolder
C2, C5: 1F; 1F_Supercap
C4: 100u; CP_Radial_D5.0mm_P2.00mm
C6, C14: 10u; C_0805_2012Metric_Pad1.18x1.45mm_HandSolder
C7: 1u; C_0805_2012Metric_Pad1.18x1.45mm_HandSolder
C8: 4.7u; C_0805_2012Metric_Pad1.18x1.45mm_HandSolder
D1, D2, D3, D4, D5, D6, D7, D8, D9, D10, D11: LED; LED_0805_2012Metric_Pad1.15x1.40mm_HandSolder
J1, J2, J3, J4, J5, J6, J7: Conn_01x06; JST_PH_B6B-PH-K_1x06_P2.00mm_Vertical
J8: Digital/PWM; PinSocket_1x10_P2.54mm_Vertical
J9: Power; PinSocket_1x08_P2.54mm_Vertical
J10: Analog; PinSocket_1x06_P2.54mm_Vertical
J11: Digital/PWM; PinSocket_1x08_P2.54mm_Vertical
L1: 10u; Power_Inductor_101040
LITH1: 18650; 18650_Cell_Clip_V2
Q1, Q2, Q3, Q4, Q5, Q6, Q7, Q8, Q9, Q10: AO3400A; SOT-23
R1, R6: 0.1R; R_Shunt_2512_V2
R2, R3, R7, R8: 10; R_0805_2012Metric_Pad1.20x1.40mm_HandSolder
R4: 1M; R_0805_2012Metric_Pad1.20x1.40mm_HandSolder
R5: 220k; R_0805_2012Metric_Pad1.20x1.40mm_HandSolder
R9: 100; R_0805_2012Metric_Pad1.20x1.40mm_HandSolder
R10, R11, R12, R13, R17, R18, R19, R20, R21, R22, R23, R24, R25: 1k; R_0805_2012Metric_Pad1.20x1.40mm_HandSolder
R14, R26, R27, R28, R29, R30, R31, R32, R33, R34: 10k; R_0805_2012Metric_Pad1.20x1.40mm_HandSolder
R15, R16: 2.2k; R_0805_2012Metric_Pad1.20x1.40mm_HandSolder
TPx1: TestPoint_Alt; TestPoint_THTPad_1.0x1.0mm_Drill0.5mm
U1, U4: INA219AxD; SOIC-8_3.9x4.9mm_P1.27mm
U2: LTC3105xMS; MSOP-12_3x4.039mm_P0.65mm
U3: AD5280; TSSOP-14_4.4x5mm_P0.65mm
U5: DW01; SOT-23-6_Handsoldering
U6: TP4056; SOIC-8-1EP_3.9x4.9mm_P1.27mm_EP2.29x3mm
U7: FS8205A; FS8205A_Wide

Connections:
!BOOST: J11.3, Q9.1 (G), R33.2, U2.4 (~SHDN)
+3V3: J9.4
/2: J11.6
/4: J11.4
/*3: J11.5
/A0: J10.1
/A1: J10.2
/A2: J10.3
/A3: J10.4
/AREF: J8.3
/IOREF: J9.2
/RX/0: J11.8
/TX/1: J11.7
/~RESET: J9.3
BAT+: LITH1.1 (+), R9.2
BAT-: C12.1, LITH1.2 (-), U5.6 (GND), U7.2 (S1), U7.3 (S1)
CHARGER: J11.2, Q1.1 (G), Q10.1 (G), R14.2, R34.2
GND: C2.2, C3.2, C4.1, C5.2, C6.2, C7.2, C8.2, C9.2, C11.2, J1.5, J2.5, J3.5, J4.5, J5.5, J6.5, J7.5, J8.4, J9.6, J9.7, Q1.2 (S), Q2.2 (S), Q3.2 (S), Q4.2 (S), Q5.2 (S), Q6.2 (S), Q7.2 (S), Q8.2 (S), Q9.2 (S), Q10.2 (S), R5.2, R14.1, R26.1, R27.1, R28.1, R29.1, R30.1, R31.1, R32.1, R33.1, R34.1, U1.1 (A1), U1.2 (A0), U1.6 (GND), U2.3 (FBLDO), U2.6 (GND), U2.7 (GND), U3.3 (B), U3.8 (AD0), U3.9 (AD1), U3.10 (GND), U3.11 (VSS), U4.2 (A0), U4.6 (GND)
L_SWITCH: L1.2, U2.9 (SWITCH)
L_VIN: C2.1, C6.1, L1.1, R1.1, U2.8 (VIN)
unnamed: C1.1, R1.2, R3.2
unnamed: C1.2, R1.3, R2.2
unnamed: C10.1, R6.2, R8.2
unnamed: C10.2, R6.3, R7.2
unnamed: C13.2, D1.2 (A), D2.2 (A), R6.1, U6.4 (VCC), U6.8 (CE)
unnamed: D1.1 (K), R10.1
unnamed: D2.1 (K), R11.1
unnamed: D3.2 (A), R17.1
unnamed: D3.1 (K), Q2.3 (D)
unnamed: D4.2 (A), R18.1
unnamed: D4.1 (K), Q3.3 (D)
unnamed: D5.2 (A), R19.1
unnamed: D5.1 (K), Q4.3 (D)
unnamed: D6.2 (A), R20.1
unnamed: D6.1 (K), Q5.3 (D)
unnamed: D7.2 (A), R21.1
unnamed: D7.1 (K), Q6.3 (D)
unnamed: D8.2 (A), R22.1
unnamed: D8.1 (K), Q7.3 (D)
unnamed: D9.2 (A), R23.1
unnamed: D9.1 (K), Q8.3 (D)
unnamed: D10.2 (A), R24.1
unnamed: D10.1 (K), Q9.3 (D)
unnamed: D11.2 (A), R25.1
unnamed: D11.1 (K), Q10.3 (D)
unnamed: C13.1, C14.1, Q1.3 (D), R12.1, R13.1, U6.1 (TEMP), U6.3 (GND), U7.6 (S2), U7.7 (S2)
unnamed: R3.1, U1.8 (IN+)
unnamed: R2.1, U1.7 (IN-)
unnamed: C7.1, U2.12 (AUX)
unnamed: R4.2, R5.1, U2.1 (FB)
unnamed: C8.1, U2.2 (LDO)
unnamed: U2.5 (MPPC), U3.2 (W)
unnamed: C4.2, C5.1, R4.1, R6.4, U2.11 (VOUT)
unnamed: TPx1.1, U2.10 (~PGOOD)
unnamed: R8.1, U4.8 (IN+)
unnamed: R7.1, U4.7 (IN-)
unnamed: R12.2, U5.2 (CS)
unnamed: U5.3 (OC), U7.5 (G2)
unnamed: U5.1 (OD), U7.4 (G1)
unnamed: C12.2, C14.2, R9.1, U5.5 (VCC), U6.5 (BAT)
unnamed: R13.2, U6.2 (PROG)
unnamed: R10.2, U6.7 (~CHRG)
unnamed: R11.2, U6.6 (~STDBY)
SCL: J1.4, J2.4, J3.4, J4.4, J5.4, J6.4, J7.4, J8.1, J10.6, R16.1, U1.4 (SCL), U3.6 (SCL), U4.4 (SCL)
SDA: J1.3, J2.3, J3.3, J4.3, J5.3, J6.3, J7.3, J8.2, J10.5, R15.1, U1.3 (SDA), U3.7 (SDA), U4.3 (SDA)
SHDN_1: J1.1, J8.5, Q2.1 (G), R26.2
SHDN_2: J2.1, J8.6, Q3.1 (G), R27.2
SHDN_3: J3.1, J8.7, Q4.1 (G), R28.2
SHDN_4: J4.1, J8.8, Q5.1 (G), R29.2
SHDN_5: J5.1, J8.9, Q6.1 (G), R30.2
SHDN_6: J6.1, J8.10, Q7.1 (G), R31.2
SHDN_7: J7.1, J11.1, Q8.1 (G), R32.2
VBUS: C3.1, C9.1, C11.1, J1.6, J2.6, J3.6, J4.6, J5.6, J6.6, J7.6, J9.5, R15.2, R16.2, R17.2, R18.2, R19.2, R20.2, R21.2, R22.2, R23.2, R24.2, R25.2, U1.5 (VS), U3.4 (VDD), U3.13 (VLOG), U4.1 (A1), U4.5 (VS)
VIN: J9.8
VOUT_1: J1.2, J2.2, J3.2, J4.2, J5.2, J6.2, J7.2, R1.4

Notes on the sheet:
INCOMING POWER MONITOR
Address: 0x40
MODULE 3
LV BOOST CONVERTER 0.250V -> 5.0V
Address: 0x2C
OUTGOING POWER MONITOR
1F SUPERCAP
18650 BMS+CHARGING MODULE
MODULE 4
ARDUINO UNO SHIELD
Address: 0x44
MODULE 1
DIGITAL POT 200K MPPC ADJUST
MODULE 5
MODULE 6
* Indicates a PWM-capable pin
MODULE 7
MODULE 2

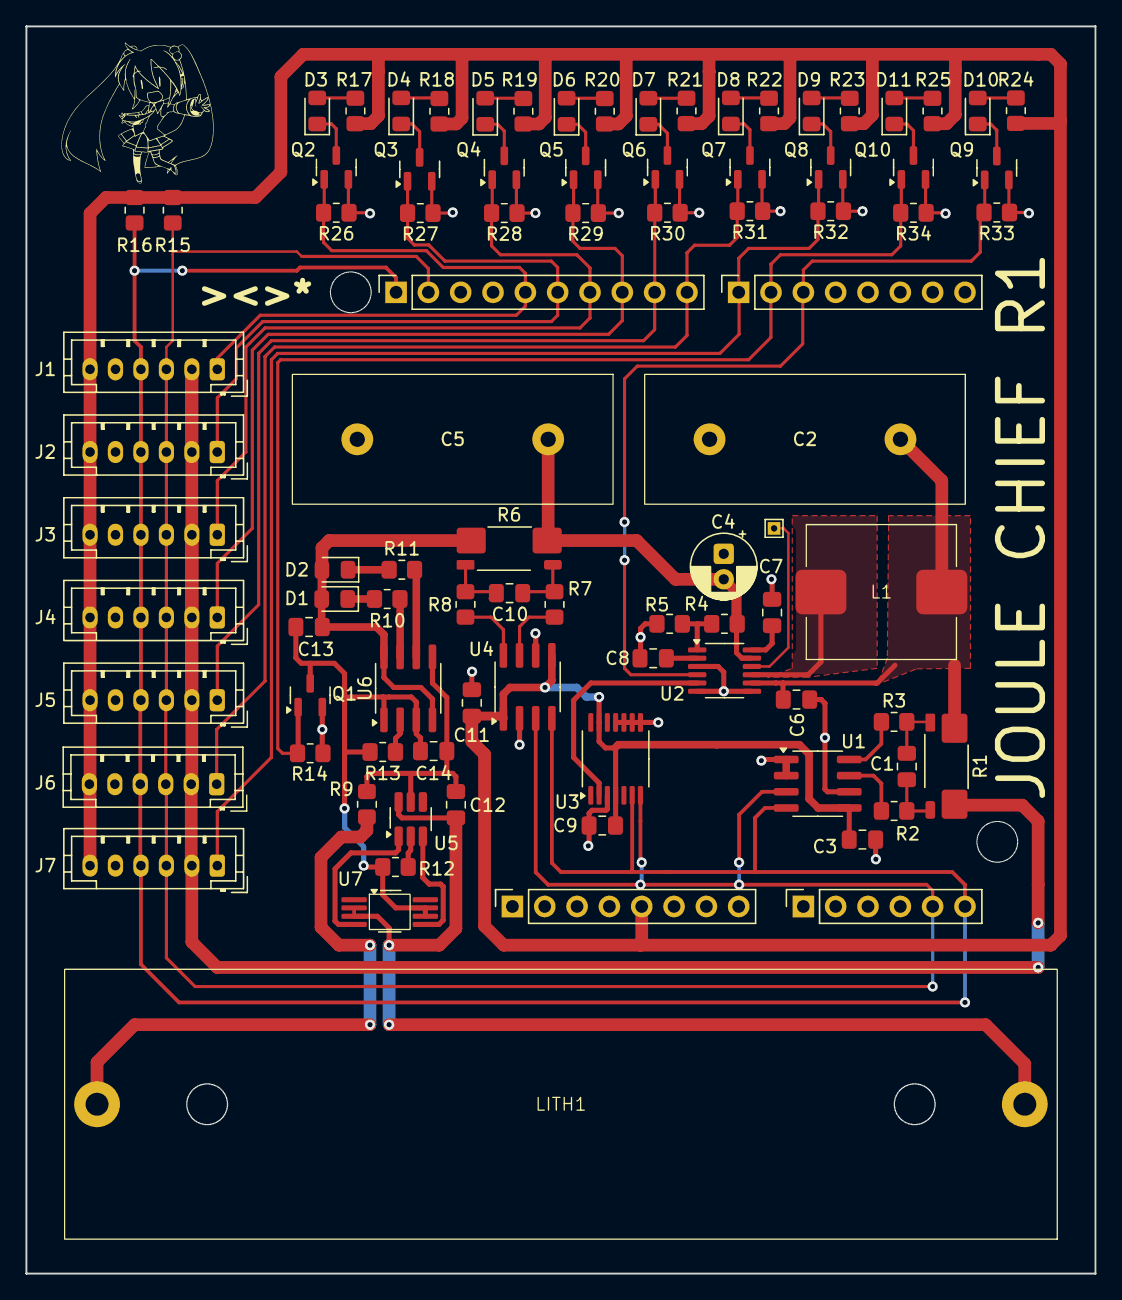
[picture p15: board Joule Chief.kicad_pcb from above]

Board: 2 copper layers, 84.0 x 98.0 mm, 92 parts (0 on the bottom side), 61 nets.

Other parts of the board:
MH1, MH4: MountingHole_3.2mm

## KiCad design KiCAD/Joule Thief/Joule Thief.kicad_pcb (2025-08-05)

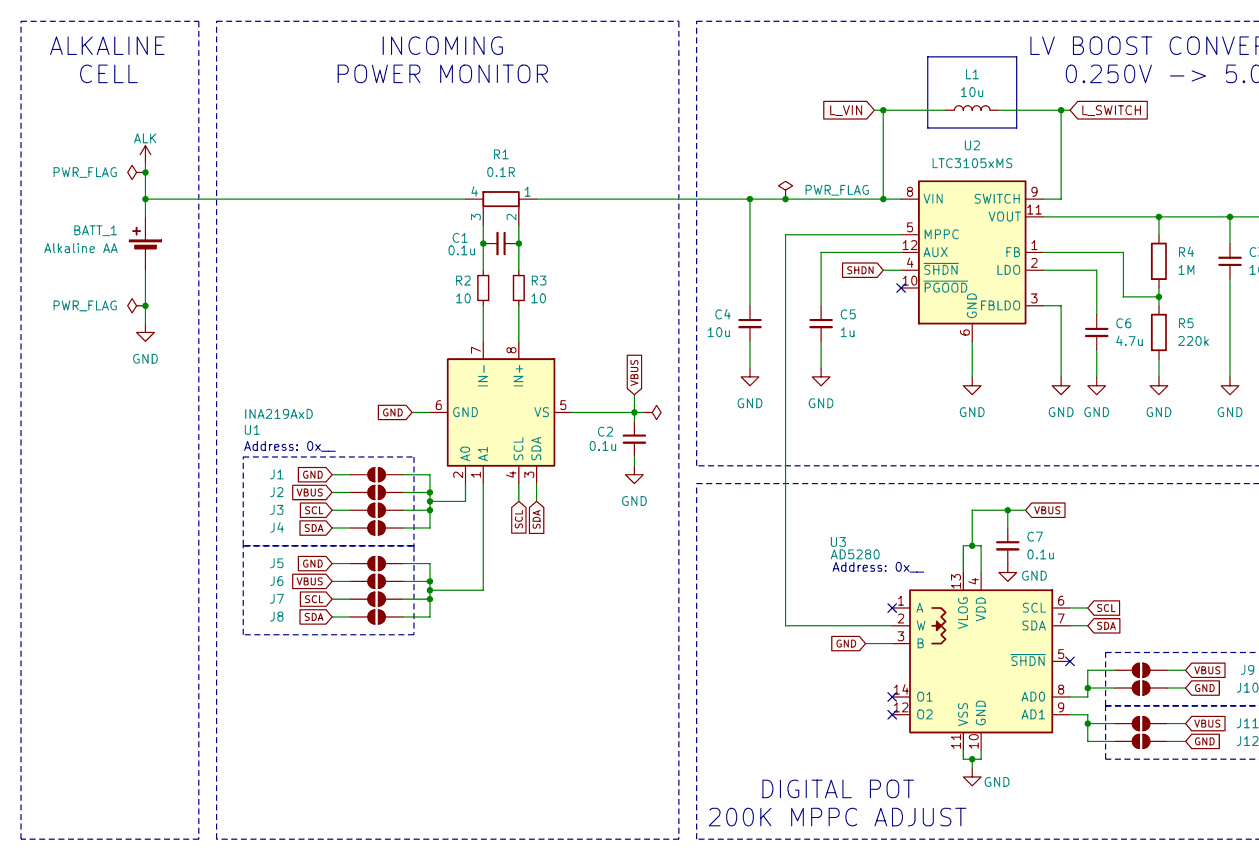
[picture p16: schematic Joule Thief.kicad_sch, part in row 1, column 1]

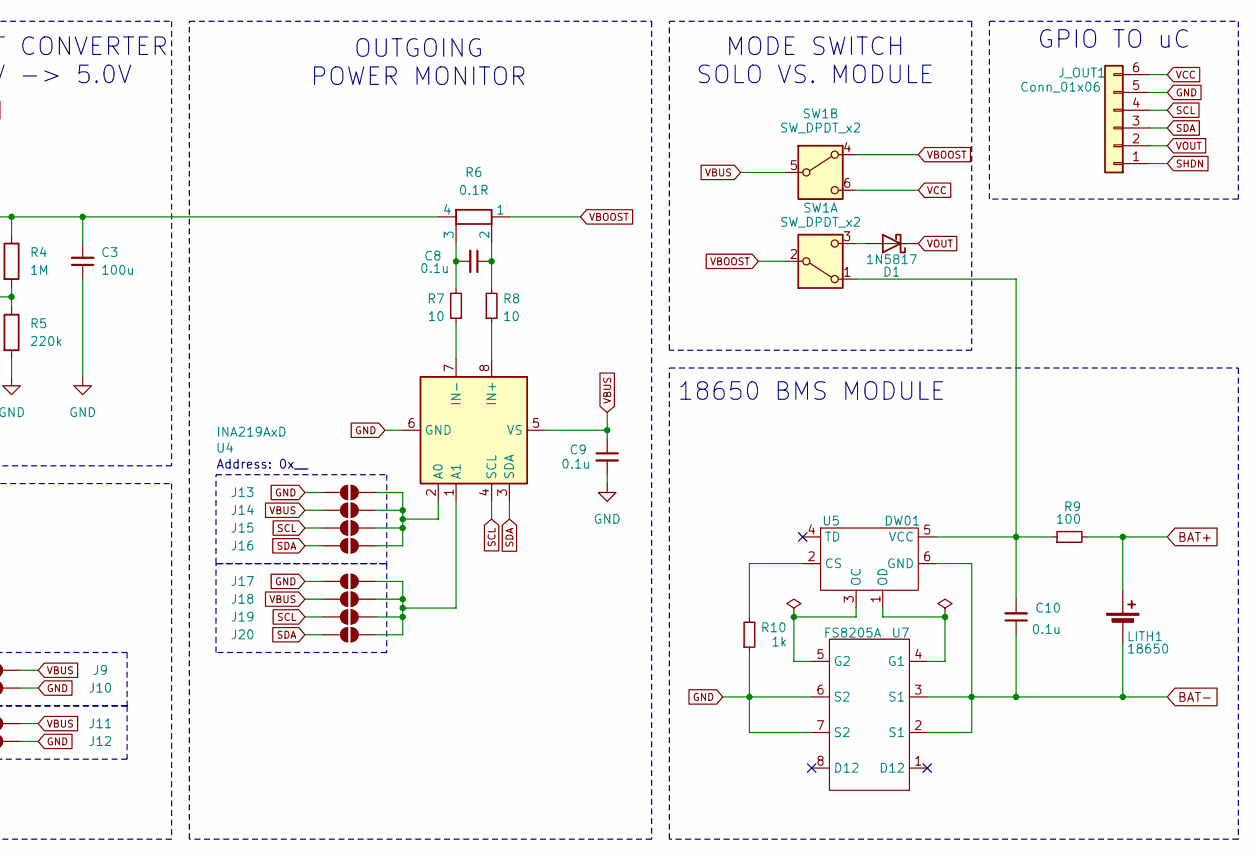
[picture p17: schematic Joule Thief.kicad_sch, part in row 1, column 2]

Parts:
BATT_1: Alkaline AA; AA_Cell_Clip_V2
C1, C2, C7, C8, C9, C10: 0.1u; C_0805_2012Metric_Pad1.18x1.45mm_HandSolder
C3: 100u; CP_Radial_D5.0mm_P2.00mm
C4: 10u; C_0805_2012Metric_Pad1.18x1.45mm_HandSolder
C5: 1u; C_0805_2012Metric_Pad1.18x1.45mm_HandSolder
C6: 4.7u; C_0805_2012Metric_Pad1.18x1.45mm_HandSolder
D1: 1N5817; D_DO-41_SOD81_P10.16mm_Horizontal
J1, J2, J3, J4, J5, J6, J7, J8, J9, J10, J11, J12, J13, J14, J15, J16, J17, J18, J19, J20: SolderJumper_2_Open; SolderJumper-2_P1.3mm_Open_RoundedPad1.0x1.5mm
J_OUT1: Conn_01x06; JST_PH_B6B-PH-K_1x06_P2.00mm_Vertical
L1: 10u; Power_Inductor_101040
LITH1: 18650; 18650_Cell_Clip_V2
R1, R6: 0.1R; R_Shunt_2512_V2
R2, R3, R7, R8: 10; R_0805_2012Metric_Pad1.20x1.40mm_HandSolder
R4: 1M; R_0805_2012Metric_Pad1.20x1.40mm_HandSolder
R5: 220k; R_0805_2012Metric_Pad1.20x1.40mm_HandSolder
R9: 100; R_0805_2012Metric_Pad1.20x1.40mm_HandSolder
R10: 1k; R_0805_2012Metric_Pad1.20x1.40mm_HandSolder
SW1: SW_DPDT_x2; SS22F25_DPDT_Straight_V2
U1, U4: INA219AxD; SOIC-8_3.9x4.9mm_P1.27mm
U2: LTC3105xMS; MSOP-12_3x4.039mm_P0.65mm
U3: AD5280; TSSOP-14_4.4x5mm_P0.65mm
U5: DW01; SOT-23-6_Handsoldering
U7: FS8205A; FS8205A_Wide

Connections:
ALK: BATT_1.1 (+), R1.4
BAT+: LITH1.1 (+), R9.2
BAT-: C10.1, LITH1.2 (-), U5.6 (GND), U7.2 (S1), U7.3 (S1)
GND: BATT_1.2 (-), C2.2, C3.1, C4.2, C5.2, C6.2, C7.2, C9.2, J1.2 (B), J5.2 (B), J10.2 (B), J12.2 (B), J13.2 (B), J17.2 (B), J_OUT1.5, R5.2, R10.1, U1.6 (GND), U2.3 (FBLDO), U2.6 (GND), U2.7 (GND), U3.3 (B), U3.10 (GND), U3.11 (VSS), U4.6 (GND), U7.6 (S2), U7.7 (S2)
L_SWITCH: L1.2, U2.9 (SWITCH)
L_VIN: C4.1, L1.1, R1.1, U2.8 (VIN)
unnamed: C1.1, R1.2, R3.2
unnamed: C1.2, R1.3, R2.2
unnamed: C8.1, R6.2, R8.2
unnamed: C8.2, R6.3, R7.2
unnamed: D1.2 (A), SW1.3 (C)
unnamed: J1.1 (A), J2.1 (A), J3.1 (A), J4.1 (A), U1.2 (A0)
unnamed: J5.1 (A), J6.1 (A), J7.1 (A), J8.1 (A), U1.1 (A1)
unnamed: J9.1 (A), J10.1 (A), U3.8 (AD0)
unnamed: J11.1 (A), J12.1 (A), U3.9 (AD1)
unnamed: J13.1 (A), J14.1 (A), J15.1 (A), J16.1 (A), U4.2 (A0)
unnamed: J17.1 (A), J18.1 (A), J19.1 (A), J20.1 (A), U4.1 (A1)
unnamed: C10.2, R9.1, SW1.1 (A), U5.5 (VCC)
unnamed: R3.1, U1.8 (IN+)
unnamed: R2.1, U1.7 (IN-)
unnamed: C5.1, U2.12 (AUX)
unnamed: R4.2, R5.1, U2.1 (FB)
unnamed: C6.1, U2.2 (LDO)
unnamed: U2.5 (MPPC), U3.2 (W)
unnamed: C3.2, R4.1, R6.4, U2.11 (VOUT)
unnamed: R8.1, U4.8 (IN+)
unnamed: R7.1, U4.7 (IN-)
unnamed: R10.2, U5.2 (CS)
unnamed: U5.3 (OC), U7.5 (G2)
unnamed: U5.1 (OD), U7.4 (G1)
SCL: J3.2 (B), J7.2 (B), J15.2 (B), J19.2 (B), J_OUT1.4, U1.4 (SCL), U3.6 (SCL), U4.4 (SCL)
SDA: J4.2 (B), J8.2 (B), J16.2 (B), J20.2 (B), J_OUT1.3, U1.3 (SDA), U3.7 (SDA), U4.3 (SDA)
SHDN: J_OUT1.1, U2.4 (~SHDN)
VBOOST: R6.1, SW1.2 (B), SW1.4 (A)
VBUS: C2.1, C7.1, C9.1, J2.2 (B), J6.2 (B), J9.2 (B), J11.2 (B), J14.2 (B), J18.2 (B), SW1.5 (B), U1.5 (VS), U3.4 (VDD), U3.13 (VLOG), U4.5 (VS)
VCC: J_OUT1.6, SW1.6 (C)
VOUT: D1.1 (K), J_OUT1.2

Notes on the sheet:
Address: 0x__
DIGITAL POT 200K MPPC ADJUST
INCOMING POWER MONITOR
ALKALINE CELL
Address: 0x__
OUTGOING POWER MONITOR
18650 BMS MODULE
MODE SWITCH SOLO VS. MODULE
GPIO TO uC
LV BOOST CONVERTER 0.250V -> 5.0V

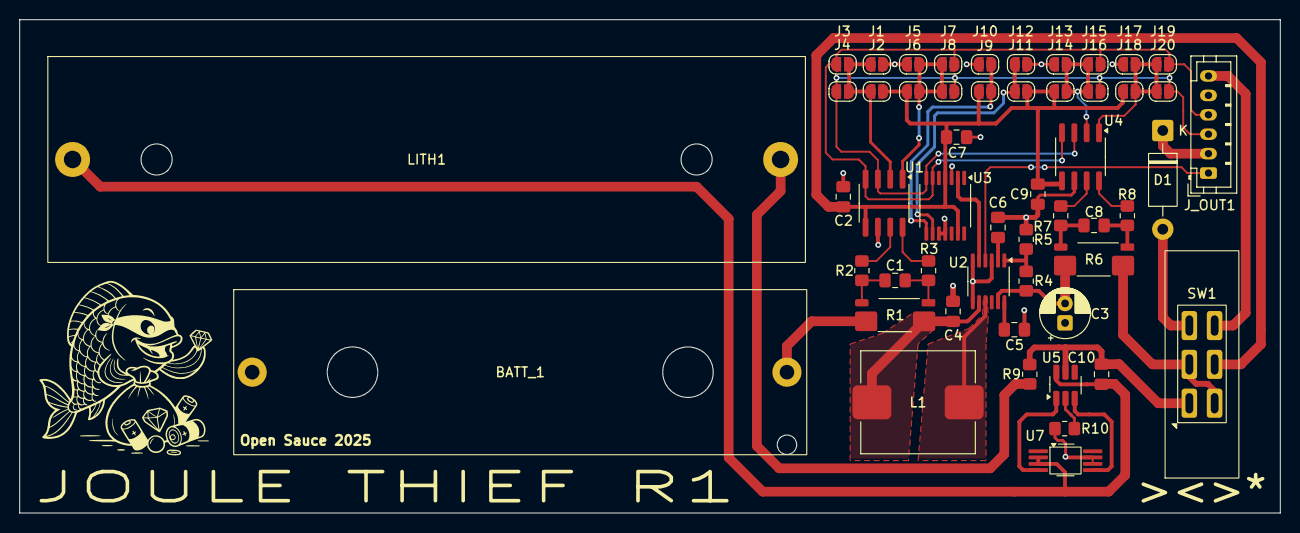
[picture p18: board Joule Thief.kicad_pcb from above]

Board: 2 copper layers, 129.8 x 50.8 mm, 52 parts (0 on the bottom side), 37 nets.

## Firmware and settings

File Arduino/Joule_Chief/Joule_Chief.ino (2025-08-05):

//Quad Channel Joule Thief - Refactored with Struct Methodology

#include <Wire.h>
#include "AD524X.h"

// ----------- ADDRESSES -----------
// Main Board (Channel A)
const uint8_t INA219_ADDR_A1 = 0x40; 
const uint8_t INA219_ADDR_A2 = 0x44;     
AD5280 AD01_A(0x2C); 
// Module 0 (Channel B)
const uint8_t INA219_ADDR_B1 = 0x4E; 
const uint8_t INA219_ADDR_B2 = 0x4F;  
AD5280 AD01_B(0x2F);  
// Module 1 (Channel C)
const uint8_t INA219_ADDR_C1 = 0x4C; 
const uint8_t INA219_ADDR_C2 = 0x4D;  
AD5280 AD01_C(0x2E);
// Module 2 (Channel D)
const uint8_t INA219_ADDR_D1 = 0x4A; 
const uint8_t INA219_ADDR_D2 = 0x4B;  
AD5280 AD01_D(0x2D);  
// Module 3 (Channel E)
const uint8_t INA219_ADDR_E1 = 0x48; 
const uint8_t INA219_ADDR_E2 = 0x49;  
AD5280 AD01_E(0x2B);

// ----------- CALIBRATION -----------
const uint16_t INA219_CONFIG = 0x05DF;      // Configuration register value
const uint16_t INA219_CALIBRATION = 0x2000; // Calibration register value

// LSB (Least Significant Bit) constants for measurements
const float CURRENT_LSB = 0.000050;        // 50µA per bit
const float POWER_LSB = 20 * CURRENT_LSB;  // ~2mW per bit
const float V_SHUNT_LSB = 0.000010;        // 10µV per bit
const float V_BUS_LSB = 0.004;             // 4mV per bit

// Booster Buffer Schmitt Trigger Parameters
const float SCHMITT_UPPER_THRESHOLD = 5;    // Upper threshold voltage
const float SCHMITT_LOWER_THRESHOLD = 4;    // Lower threshold voltage
bool schmittState = false;                  // Current state of Schmitt trigger output

// Charger Buffer Schmitt Trigger Parameters
const float SCHMITT_UPPER_THRESHOLD_2 = 5.25; // Upper threshold voltage for boost
const float SCHMITT_LOWER_THRESHOLD_2 = 4.25; // Lower threshold voltage for boost
bool schmittState2 = false;                    // Current state of second Schmitt trigger output

// ----------- DECLARATIONS -----------
// Analog and Digital I/O Pin Definitions
const int BOOST_PIN = 5;    // Chief Booster Enable HIGH
const int CHARGE_PIN = 6;   // Chief Charger Enable HIGH
const int SHDN_0_PIN = 13;  // Pull LOW to SHDN Module 0
const int SHDN_1_PIN = 12;  // Pull LOW to SHDN Module 1
const int SHDN_2_PIN = 11;  // Pull LOW to SHDN Module 2
const int SHDN_3_PIN = 10;  // Pull LOW to SHDN Module 3

// ----------- CHANNEL DATA STRUCTURE -----------
struct ChannelData {
  uint8_t inputSensorAddr;   // Input sensor address
  uint8_t outputSensorAddr;  // Output sensor address
  AD5280* digitalPot;        // Pointer to digital potentiometer
  float currentSourceVoltage;
  float powerIn;
  float powerOut;
  float efficiency;
  bool mppcEnabled;
  uint8_t mppcValue;
  bool mpptInitialized;
  char channelId;
  // MPPT variables
  float previousPowerOut;
  int mpptStepSize;
  int mpptDirection;
};

// ----------- GLOBAL VARIABLES -----------
// Channel A special variables (kept separate due to unique behavior)
int mppcValueA = 128;
float powerInA = 0.0;
float powerOutA = 0.0;
float efficiencyA = 0.0;
float currentSourceVoltageA = 0.0;
bool mppcEnabledA = false;
float previousPowerOutA = 0.0;  // Changed from previousEfficiencyA
int mpptStepSizeA = 5;
int mpptDirectionA = 1;
bool mpptInitializedA = false;

// Array of channels B through E
ChannelData channels[4];

// ----------- FUNCTION DECLARATIONS -----------
uint16_t readReg16(uint8_t addr, uint8_t reg);
void writeReg16(uint8_t addr, uint8_t reg, uint16_t value);
bool isConversionReady(uint8_t addr);
float readBusVoltage(uint8_t addr);
float readShuntVoltage(uint8_t addr);
float readCurrent(uint8_t addr);
float readPower(uint8_t addr);
void dumpRegisters(uint8_t addr);
void setMPPC_A(int potValue);
void updateMPPT_A();
void processChannelInput(ChannelData& channel);
void processChannelOutput(ChannelData& channel);
void setChannelMPPC(ChannelData& channel, uint8_t value);
void updateChannelMPPT(ChannelData& channel);
void initializeChannels();

// ----------- Setup -----------
void setup() {
  Serial.begin(115200);
  Wire.begin();
  Wire.setClock(400000);  // Set I2C clock to 400kHz for all devices

  // Initialize digital I/O pins
  pinMode(BOOST_PIN, OUTPUT);
  digitalWrite(BOOST_PIN, LOW);
  pinMode(CHARGE_PIN, OUTPUT);
  digitalWrite(CHARGE_PIN, LOW);
  pinMode(SHDN_0_PIN, OUTPUT);
  digitalWrite(SHDN_0_PIN, HIGH);
  pinMode(SHDN_1_PIN, OUTPUT);
  digitalWrite(SHDN_1_PIN, HIGH);
  pinMode(SHDN_2_PIN, OUTPUT);
  digitalWrite(SHDN_2_PIN, HIGH);
  pinMode(SHDN_3_PIN, OUTPUT);
  digitalWrite(SHDN_3_PIN, HIGH);

  // Initialize channels array
  initializeChannels();

  // ----------- AD5280 INIT -----------
  // Initialize Channel A AD5280 digital potentiometer
  bool adConnectedA = AD01_A.begin();
  Serial.print(F("Channel A AD5280 connected: "));
  Serial.println(adConnectedA ? F("true") : F("false"));
  
  // Initialize channels B-E digital potentiometers
  for (int i = 0; i < 4; i++) {
    bool adConnected = channels[i].digitalPot->begin();
    Serial.print(F("Channel "));
    Serial.print(channels[i].channelId);
    Serial.print(F(" AD5280 connected: "));
    Serial.println(adConnected ? F("true") : F("false"));
  }

  // ----------- INA219 INIT -----------
  // Configure Channel A INA219 sensors
  writeReg16(INA219_ADDR_A1, 0x00, INA219_CONFIG);
  writeReg16(INA219_ADDR_A1, 0x05, INA219_CALIBRATION);
  writeReg16(INA219_ADDR_A2, 0x00, INA219_CONFIG);
  writeReg16(INA219_ADDR_A2, 0x05, INA219_CALIBRATION);
  
  // Configure channels B-E INA219 sensors
  for (int i = 0; i < 4; i++) {
    writeReg16(channels[i].inputSensorAddr, 0x00, INA219_CONFIG);
    writeReg16(channels[i].inputSensorAddr, 0x05, INA219_CALIBRATION);
    writeReg16(channels[i].outputSensorAddr, 0x00, INA219_CONFIG);
    writeReg16(channels[i].outputSensorAddr, 0x05, INA219_CALIBRATION);
  }

  Serial.println(F("All INA219 sensors initialized"));
  Serial.println(F("All I2C devices ready"));
}

// Initialize channels array
void initializeChannels() {
  // Channel B (index 0)
  channels[0].inputSensorAddr = INA219_ADDR_B1;
  channels[0].outputSensorAddr = INA219_ADDR_B2;
  channels[0].digitalPot = &AD01_B;
  channels[0].currentSourceVoltage = 0.0;
  channels[0].powerIn = 0.0;
  channels[0].powerOut = 0.0;
  channels[0].efficiency = 0.0;
  channels[0].mppcEnabled = false;
  channels[0].mppcValue = 128;
  channels[0].mpptInitialized = false;
  channels[0].channelId = 'B';
  channels[0].previousPowerOut = 0.0;
  channels[0].mpptStepSize = 5;
  channels[0].mpptDirection = 1;
  
  // Channel C (index 1)
  channels[1].inputSensorAddr = INA219_ADDR_C1;
  channels[1].outputSensorAddr = INA219_ADDR_C2;
  channels[1].digitalPot = &AD01_C;
  channels[1].currentSourceVoltage = 0.0;
  channels[1].powerIn = 0.0;
  channels[1].powerOut = 0.0;
  channels[1].efficiency = 0.0;
  channels[1].mppcEnabled = false;
  channels[1].mppcValue = 128;
  channels[1].mpptInitialized = false;
  channels[1].channelId = 'C';
  channels[1].previousPowerOut = 0.0;
  channels[1].mpptStepSize = 5;
  channels[1].mpptDirection = 1;
  
  // Channel D (index 2)
  channels[2].inputSensorAddr = INA219_ADDR_D1;
  channels[2].outputSensorAddr = INA219_ADDR_D2;
  channels[2].digitalPot = &AD01_D;
  channels[2].currentSourceVoltage = 0.0;
  channels[2].powerIn = 0.0;
  channels[2].powerOut = 0.0;
  channels[2].efficiency = 0.0;
  channels[2].mppcEnabled = false;
  channels[2].mppcValue = 128;
  channels[2].mpptInitialized = false;
  channels[2].channelId = 'D';
  channels[2].previousPowerOut = 0.0;
  channels[2].mpptStepSize = 5;
  channels[2].mpptDirection = 1;
  
  // Channel E (index 3)
  channels[3].inputSensorAddr = INA219_ADDR_E1;
  channels[3].outputSensorAddr = INA219_ADDR_E2;
  channels[3].digitalPot = &AD01_E;
  channels[3].currentSourceVoltage = 0.0;
  channels[3].powerIn = 0.0;
  channels[3].powerOut = 0.0;
  channels[3].efficiency = 0.0;
  channels[3].mppcEnabled = false;
  channels[3].mppcValue = 128;
  channels[3].mpptInitialized = false;
  channels[3].channelId = 'E';
  channels[3].previousPowerOut = 0.0;
  channels[3].mpptStepSize = 5;
  channels[3].mpptDirection = 1;
}

// ─────────────────────────── Main Loop ───────────────────────────
void loop() {
  // ===== CHANNEL A (Special handling) =====
  // Read Channel A input measurements from sensor A1
  if (isConversionReady(INA219_ADDR_A1)) {
    float sourceVoltageA = readBusVoltage(INA219_ADDR_A1);
    currentSourceVoltageA = sourceVoltageA;
    float currentInA = readCurrent(INA219_ADDR_A1);
    powerInA = readPower(INA219_ADDR_A1);
    
    // Check if MPPC should be enabled/disabled based on source voltage
    if (currentSourceVoltageA >= 0.3) {
      mppcEnabledA = true;
    } else {
      if (mppcEnabledA) {
        mppcValueA = 128;
        setMPPC_A(mppcValueA);
        mpptInitializedA = false;
      }
      mppcEnabledA = false;
    }
    
    Serial.print("source_voltage_a=");
    Serial.print(sourceVoltageA, 2);
    Serial.print(",power_in_a=");
    Serial.print(powerInA * 1000, 2);
    Serial.print(",current_in_a=");
    Serial.print(currentInA * -1000, 2);
    Serial.print(",mppc_a=");
    Serial.print(mppcValueA);
    Serial.print(",mppc_enabled_a=");
    Serial.print(mppcEnabledA ? 1 : 0);
    Serial.print(",schmitt_1=");
    Serial.print(schmittState ? 1: 0);
    Serial.print(",schmitt_2=");
    Serial.print(schmittState2 ? 1: 0);
    Serial.println();

    // ===== SCHMITT TRIGGER DIGITAL OUTPUT CONTROL =====
    if (schmittState == false) {
      if (sourceVoltageA >= SCHMITT_UPPER_THRESHOLD) {
        schmittState = true;
        digitalWrite(BOOST_PIN, HIGH);
      }
    } else {
      if (sourceVoltageA <= SCHMITT_LOWER_THRESHOLD) {
        schmittState = false;
        digitalWrite(BOOST_PIN, LOW);
      }
    }
  }

  // Read Channel A output measurements from sensor A2
  if (isConversionReady(INA219_ADDR_A2)) {
    float boostVoltageA = readBusVoltage(INA219_ADDR_A2);
    float currentOutA = readCurrent(INA219_ADDR_A2);
    powerOutA = readPower(INA219_ADDR_A2);
    
    if (powerInA > 0) {
      efficiencyA = (powerOutA / powerInA) * 100.0;
    }
    
    Serial.print("boost_voltage_a=");
    Serial.print(boostVoltageA, 2);
    Serial.print(",power_out_a=");
    Serial.print(powerOutA * 1000, 2);
    Serial.print(",current_out_a=");
    Serial.print(currentOutA * -1000, 2);
    Serial.print(",efficiency_a=");
    Serial.print(efficiencyA, 6);
    Serial.println();

    updateMPPT_A();

    // ===== SECOND SCHMITT TRIGGER FOR BOOST VOLTAGE =====
    if (schmittState2 == false) {
      if (boostVoltageA >= SCHMITT_UPPER_THRESHOLD_2) {
        schmittState2 = true;
        digitalWrite(CHARGE_PIN, HIGH);
      }
    } else {
      if (boostVoltageA <= SCHMITT_LOWER_THRESHOLD_2) {
        schmittState2 = false;
        digitalWrite(CHARGE_PIN, LOW);
      }
    }
  }

  // ===== CHANNELS B-E (Struct-based processing) =====
  for (int i = 0; i < 4; i++) {
    processChannelInput(channels[i]);
    processChannelOutput(channels[i]);
  }
}

// Process input sensor for a channel
void processChannelInput(ChannelData& channel) {
  if (isConversionReady(channel.inputSensorAddr)) {
    float sourceVoltage = readBusVoltage(channel.inputSensorAddr);
    channel.currentSourceVoltage = sourceVoltage;
    float currentIn = readCurrent(channel.inputSensorAddr);
    channel.powerIn = readPower(channel.inputSensorAddr);
    
    // Check if MPPC should be enabled/disabled based on source voltage
    if (channel.currentSourceVoltage >= 0.3) {
      channel.mppcEnabled = true;
    } else {
      if (channel.mppcEnabled) {
        channel.mppcValue = 128;
        setChannelMPPC(channel, channel.mppcValue);
        channel.mpptInitialized = false;
      }
      channel.mppcEnabled = false;
    }
    
    // Serial output
    char channelLower = tolower(channel.channelId);
    Serial.print("source_voltage_");
    Serial.print(channelLower);
    Serial.print("=");
    Serial.print(sourceVoltage, 2);
    Serial.print(",power_in_");
    Serial.print(channelLower);
    Serial.print("=");
    Serial.print(channel.powerIn * 1000, 2);
    Serial.print(",current_in_");
    Serial.print(channelLower);
    Serial.print("=");
    Serial.print(currentIn * -1000, 2);
    Serial.print(",mppc_");
    Serial.print(channelLower);
    Serial.print("=");
    Serial.print(channel.mppcValue);
    Serial.print(",mppc_enabled_");
    Serial.print(channelLower);
    Serial.print("=");
    Serial.print(channel.mppcEnabled ? 1 : 0);
    Serial.println();
  }
}

// Process output sensor for a channel
void processChannelOutput(ChannelData& channel) {
  if (isConversionReady(channel.outputSensorAddr)) {
    float boostVoltage = readBusVoltage(channel.outputSensorAddr);
    float currentOut = readCurrent(channel.outputSensorAddr);
    channel.powerOut = readPower(channel.outputSensorAddr);
    
    // Calculate efficiency
    if (channel.powerIn > 0) {
      channel.efficiency = (channel.powerOut / channel.powerIn) * 100.0;
    }
    
    // Serial output
    char channelLower = tolower(channel.channelId);
    Serial.print("boost_voltage_");
    Serial.print(channelLower);
    Serial.print("=");
    Serial.print(boostVoltage, 2);
    Serial.print(",power_out_");
    Serial.print(channelLower);
    Serial.print("=");
    Serial.print(channel.powerOut * 1000, 2);
    Serial.print(",current_out_");
    Serial.print(channelLower);
    Serial.print("=");
    Serial.print(currentOut * -1000, 2);
    Serial.print(",efficiency_");
    Serial.print(channelLower);
    Serial.print("=");
    Serial.print(channel.efficiency, 6);
    Serial.println();

    // Update MPPT
    updateChannelMPPT(channel);
  }
}

// Set MPPC value for specific channel
void setChannelMPPC(ChannelData& channel, uint8_t value) {
  if (value < 0) value = 0;
  if (value > 255) value = 255;
  channel.digitalPot->write(value);
}

// Update MPPT for specific channel
void updateChannelMPPT(ChannelData& channel) {
  // Only run MPPT if channel is enabled
  if (!channel.mppcEnabled) {
    return;
  }
  
  // Initialize on first run
  if (!channel.mpptInitialized) {
    channel.previousPowerOut = channel.powerOut;
    channel.mpptInitialized = true;
    return;
  }
  
  // Calculate power change
  float powerChange = channel.powerOut - channel.previousPowerOut;
  
  // Hill-climbing algorithm
  if (powerChange > 0) {
    // Power increased, continue in the same direction
  } else if (powerChange < 0) {
    // Power decreased, reverse direction
    channel.mpptDirection = -channel.mpptDirection;
  }
  
  // Calculate new MPPC value
  int newMppcValue = channel.mppcValue + (channel.mpptStepSize * channel.mpptDirection);
  
  // Clamp to valid range (0-255)
  if (newMppcValue < 0) {
    newMppcValue = 0;
    channel.mpptDirection = 1;
  } else if (newMppcValue > 255) {
    newMppcValue = 255;
    channel.mpptDirection = -1;
  }
  
  // Update MPPC value and apply it
  channel.mppcValue = newMppcValue;
  setChannelMPPC(channel, channel.mppcValue);
  
  // Store current power for next iteration
  channel.previousPowerOut = channel.powerOut;
}

// ────────────────────────── Original Function Definitions ──────────────────────────

/* Read 16-bit register from INA219 */
uint16_t readReg16(uint8_t addr, uint8_t reg) {
  Wire.beginTransmission(addr);
  Wire.write(reg);
  Wire.endTransmission(false);              // Repeated start

  Wire.requestFrom(addr, (uint8_t)2);
  while (Wire.available() < 2);             // Wait for data

  uint16_t val = (uint16_t)Wire.read() << 8; // MSB
  val |= Wire.read();                        // LSB
  return val;
}

/* Write 16-bit value to INA219 register */
void writeReg16(uint8_t addr, uint8_t reg, uint16_t value) {
  Wire.beginTransmission(addr);
  Wire.write(reg);
  Wire.write((uint8_t)(value >> 8));        // MSB
  Wire.write((uint8_t)(value & 0xFF));      // LSB
  Wire.endTransmission();
}

/* Check if conversion is ready */
bool isConversionReady(uint8_t addr) {
  uint16_t rawBus = readReg16(addr, 0x02);  // Bus voltage register
  return rawBus & 0x0002;                   // Bit 1: Conversion Ready Flag
}

/* Read bus voltage in Volts */
float readBusVoltage(uint8_t addr) {
  uint16_t rawBus = readReg16(addr, 0x02);
  uint16_t busData = rawBus >> 3;           // Ignore 3 LSBs
  return busData * V_BUS_LSB;
}

/* Read shunt voltage in Volts */
float readShuntVoltage(uint8_t addr) {
  uint16_t rawShunt = readReg16(addr, 0x01);
  int16_t signedShunt = (int16_t)rawShunt;  // Handle two's complement
  return signedShunt * V_SHUNT_LSB;
}

/* Read current in Amps */
float readCurrent(uint8_t addr) {
  uint16_t rawCurrent = readReg16(addr, 0x04);
  int16_t signedCurrent = (int16_t)rawCurrent; // Handle two's complement
  return signedCurrent * CURRENT_LSB;
}

/* Read power in Watts */
float readPower(uint8_t addr) {
  uint16_t rawPower = readReg16(addr, 0x03);
  return rawPower * POWER_LSB;
}

/* Optional: Debug function to dump all registers */
void dumpRegisters(uint8_t addr) {
  uint16_t cfg  = readReg16(addr, 0x00);
  uint16_t shnt = readReg16(addr, 0x01);
  uint16_t bus  = readReg16(addr, 0x02);
  uint16_t pwr  = readReg16(addr, 0x03);
  uint16_t cur  = readReg16(addr, 0x04);
  uint16_t cal  = readReg16(addr, 0x05);

  Serial.print(F("INA219 Registers - CFG:0x"));
  Serial.print(cfg, HEX);
  Serial.print(F(" SHUNT:0x"));
  Serial.print(shnt, HEX);
  Serial.print(F(" BUS:0x"));
  Serial.print(bus, HEX);
  Serial.print(F(" PWR:0x"));
  Serial.print(pwr, HEX);
  Serial.print(F(" CUR:0x"));
  Serial.print(cur, HEX);
  Serial.print(F(" CAL:0x"));
  Serial.print(cal, HEX);
  Serial.println();
}

/* Set Channel A MPPC by writing digital potentiometer value (0-255) */
void setMPPC_A(int potValue) {
  if (potValue < 0) potValue = 0;
  if (potValue > 255) potValue = 255;
  AD01_A.write(potValue);
}

/* Hill-climbing MPPT algorithm for Channel A - optimized for power output */
void updateMPPT_A() {
  // Only run MPPT if Channel A is enabled
  if (!mppcEnabledA) {
    return;
  }
  
  // Initialize on first run
  if (!mpptInitializedA) {
    previousPowerOutA = powerOutA;
    mpptInitializedA = true;
    return;
  }
  
  // Calculate power change
  float powerChange = powerOutA - previousPowerOutA;
  
  // Hill-climbing algorithm for power output optimization
  if (powerChange > 0) {
    // Power increased, continue in the same direction
  } else if (powerChange < 0) {
    // Power decreased, reverse direction
    mpptDirectionA = -mpptDirectionA;
  }
  
  // Calculate new MPPC value
  int newMppcValue = mppcValueA + (mpptStepSizeA * mpptDirectionA);
  
  // Clamp to valid range (0-255)
  if (newMppcValue < 0) {
    newMppcValue = 0;
    mpptDirectionA = 1;
  } else if (newMppcValue > 255) {
    newMppcValue = 255;
    mpptDirectionA = -1;
  }
  
  // Update MPPC value and apply it
  mppcValueA = newMppcValue;
  setMPPC_A(mppcValueA);
  
  // Store current power output for next iteration
  previousPowerOutA = powerOutA;
}

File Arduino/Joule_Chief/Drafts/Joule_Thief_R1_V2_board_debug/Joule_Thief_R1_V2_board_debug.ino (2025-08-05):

//TRIPLE CHANNEL A, B & C MPPC CONTROLLER - SIMPLIFIED

#include <Wire.h>
#include "AD524X.h"

// // INA219 Configuration for Channel A
// const uint8_t INA219_ADDR_A1 = 0x40;         // Channel A Input (A0=GND, A1=GND)
// const uint8_t INA219_ADDR_A2 = 0x41;         // Channel A Output (A0=VDD, A1=GND)
// // INA219 Configuration for Channel B  
// const uint8_t INA219_ADDR_B1 = 0x44;         // Channel B Input (A0=GND, A1=GND)
// const uint8_t INA219_ADDR_B2 = 0x45;         // Channel B Output (A0=VDD, A1=GND)
// // INA219 Configuration for Channel C
const uint8_t INA219_ADDR_C1 = 0x4E;         // Channel C Input (A0=GND, A1=VDD)
const uint8_t INA219_ADDR_C2 = 0x4F;         // Channel C Output (A0=VDD, A1=VDD)

const uint16_t INA219_CONFIG = 0x05DF;      // Configuration register value
const uint16_t INA219_CALIBRATION = 0x2000; // Calibration register value

// LSB (Least Significant Bit) constants for measurements
const float CURRENT_LSB = 0.000050;        // 50µA per bit
const float POWER_LSB = 20 * CURRENT_LSB;  // ~2mW per bit
const float V_SHUNT_LSB = 0.000010;        // 10µV per bit
const float V_BUS_LSB = 0.004;             // 4mV per bit

// AD5280 Digital Potentiometers
AD5280 AD01_A(0x2C);  // Channel A - AD0 & AD1 == GND
AD5280 AD01_B(0x2D);  // Channel B - AD0 & AD1 == GND
AD5280 AD01_C(0x2F);  // Channel C - AD0 & AD1 == GND

// Analog and Digital I/O Pin Definitions
const int ANALOG_INPUT_PIN = A0;     // Analog input pin for supercap monitoring
const int DIGITAL_OUTPUT_PIN = 13;   // Digital output pin for status indication
const int DIGITAL_OUTPUT_PIN_2 = 12; // Second digital output pin for boost voltage monitoring

// Schmitt Trigger Parameters
const float SCHMITT_UPPER_THRESHOLD = 4.5;    // Upper threshold voltage
const float SCHMITT_LOWER_THRESHOLD = 2.0;    // Lower threshold voltage
const float SCHMITT_HYSTERESIS = 0;           // Hysteresis value
bool schmittState = false;                     // Current state of Schmitt trigger output

// Second Schmitt Trigger Parameters for boost voltage monitoring
const float SCHMITT_UPPER_THRESHOLD_2 = 5.25; // Upper threshold voltage for boost
const float SCHMITT_LOWER_THRESHOLD_2 = 4.75; // Lower threshold voltage for boost
const float SCHMITT_HYSTERESIS_2 = 0;         // Hysteresis value for boost trigger
bool schmittState2 = false;                   // Current state of second Schmitt trigger output

// Global variables for Channel A
int mppcValueA = 128;  // Default to middle value (roughly 1.0V for 2V range)
float powerInA = 0.0;
float powerOutA = 0.0;
float efficiencyA = 0.0;
float currentSourceVoltageA = 0.0;
bool mppcEnabledA = false;

// Global variables for Channel B
int mppcValueB = 128;  // Default to middle value (roughly 1.0V for 2V range)
float powerInB = 0.0;
float powerOutB = 0.0;
float efficiencyB = 0.0;
float currentSourceVoltageB = 0.0;
bool mppcEnabledB = false;

// Global variables for Channel C
int mppcValueC = 128;   // Default to roughly 1.0V for 5V range (51/255 * 5V ≈ 1V)
float powerInC = 0.0;
float powerOutC = 0.0;
float efficiencyC = 0.0;
float currentSourceVoltageC = 0.0;
bool mppcEnabledC = false;

// Hill-climbing MPPT variables for Channel B
float previousPowerOutB = 0.0;         // Previous power output for comparison
int mpptStepSizeB = 5;                 // Step size for MPPT adjustment
int mpptDirectionB = 1;                // Direction of last step (1 or -1)
bool mpptInitializedB = false;         // Flag to track if MPPT has been initialized

// Hill-climbing MPPT variables for Channel C
float previousPowerOutC = 0.0;         // Previous power output for comparison
int mpptStepSizeC = 5;                 // Step size for MPPT adjustment
int mpptDirectionC = 1;                // Direction of last step (1 or -1)
bool mpptInitializedC = false;         // Flag to track if MPPT has been initialized

// ────────────────────────── Function Declarations ──────────────────────────

uint16_t readReg16(uint8_t addr, uint8_t reg);
void writeReg16(uint8_t addr, uint8_t reg, uint16_t value);
bool isConversionReady(uint8_t addr);
float readBusVoltage(uint8_t addr);
float readShuntVoltage(uint8_t addr);
float readCurrent(uint8_t addr);
float readPower(uint8_t addr);
void dumpRegisters(uint8_t addr);
void setMPPC_A(int potValue);
void setMPPC_B(int potValue);
void setMPPC_C(int potValue);
void updateMPPT_B();  // New function for Channel B MPPT
void updateMPPT_C();  // New function for Channel C MPPT

// ─────────────────────────── Setup ───────────────────────────

void setup() {
  Serial.begin(115200);
  Wire.begin();
  Wire.setClock(400000);  // Set I2C clock to 400kHz for all devices

  // Initialize digital I/O pins
  pinMode(DIGITAL_OUTPUT_PIN, OUTPUT);
  digitalWrite(DIGITAL_OUTPUT_PIN, LOW);  // Initialize digital output to LOW
  pinMode(DIGITAL_OUTPUT_PIN_2, OUTPUT);
  digitalWrite(DIGITAL_OUTPUT_PIN_2, LOW);  // Initialize second digital output to LOW

  // // Initialize Channel A AD5280 digital potentiometer
  // bool adConnectedA = AD01_A.begin();
  // Serial.print(F("Channel A AD5280 connected: "));
  // Serial.println(adConnectedA ? F("true") : F("false"));
  
  // // Initialize Channel B AD5280 digital potentiometer
  // bool adConnectedB = AD01_B.begin();
  // Serial.print(F("Channel B AD5280 connected: "));
  // Serial.println(adConnectedB ? F("true") : F("false"));

  // Initialize Channel C AD5280 digital potentiometer
  bool adConnectedC = AD01_C.begin();
  Serial.print(F("Channel C AD5280 connected: "));
  Serial.println(adConnectedC ? F("true") : F("false"));

  // // Configure Channel A INA219 sensors
  // writeReg16(INA219_ADDR_A1, 0x00, INA219_CONFIG);      // Config register
  // writeReg16(INA219_ADDR_A1, 0x05, INA219_CALIBRATION); // Calibration register
  // writeReg16(INA219_ADDR_A2, 0x00, INA219_CONFIG);      // Config register
  // writeReg16(INA219_ADDR_A2, 0x05, INA219_CALIBRATION); // Calibration register

  // // Configure Channel B INA219 sensors
  // writeReg16(INA219_ADDR_B1, 0x00, INA219_CONFIG);      // Config register
  // writeReg16(INA219_ADDR_B1, 0x05, INA219_CALIBRATION); // Calibration register
  // writeReg16(INA219_ADDR_B2, 0x00, INA219_CONFIG);      // Config register
  // writeReg16(INA219_ADDR_B2, 0x05, INA219_CALIBRATION); // Calibration register

  // Configure Channel C INA219 sensors
  writeReg16(INA219_ADDR_C1, 0x00, INA219_CONFIG);      // Config register
  writeReg16(INA219_ADDR_C1, 0x05, INA219_CALIBRATION); // Calibration register
  writeReg16(INA219_ADDR_C2, 0x00, INA219_CONFIG);      // Config register
  writeReg16(INA219_ADDR_C2, 0x05, INA219_CALIBRATION); // Calibration register

  Serial.println(F("All INA219 sensors initialized"));
  Serial.println(F("All I2C devices ready"));
}

// ─────────────────────────── Main Loop ───────────────────────────
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

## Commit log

2025-03-05 wire up batteries
    [Joule-Thief.kicad_pcb, Joule-Thief.kicad_sch]
2025-03-14 new pcb revision
    [Joule-Thief.kicad_pcb, Joule-Thief.kicad_sch, Joule-Thief_R0 - Less Messy.kicad_pcb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]
2025-03-15 made pcb r3, start r4
    [Joule-Thief_R2.kicad_pcb, Joule-Thief_R3.kicad_pcb, Joule-Thief_R4.kicad_pcb]
2025-03-15 r5 is the one bro i swear
    [Joule-Thief_R5.kicad_pcb]
2025-03-19 board ordered
    [Joule-Thief_R6-B_Cu.gbl, Joule-Thief_R6-B_Mask.gbs, Joule-Thief_R6-B_Paste.gbp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]
2025-06-23 INA219 firmware+LTC3105 breakout
    [Joule-Thief.kicad_pcb, Joule-Thief_R0 - Less Messy.kicad_pcb, Joule-Thief_R0 - Very Messy.kicad_pcb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]
2025-06-30 fw dev + r1 schematic
    [Joule_Thief_R1.kicad_pcb, Joule_Thief_R1.kicad_sch]
2025-07-01 joule chief shield schematic
    [Joule Chief Shield R1.kicad_pcb, Joule Chief Shield R1.kicad_sch, Joule_Thief_R1.kicad_sch]
2025-07-01 both schematics finished
    [Joule Chief Shield R1.kicad_sch, Joule_Thief_R1.kicad_sch]
2025-07-01 ERC+prep for board layout
    [Joule Chief Shield R1.kicad_pcb, Joule Chief Shield R1.kicad_sch]
2025-07-03 layout extraction module
    [Joule Chief Shield R1.kicad_pcb, Joule Chief Shield R1.kicad_sch, Joule_Thief_R1.kicad_pcb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]
2025-08-05 repo cleanup for final writeup
    [Joule Chief Shield R1.kicad_pcb, Joule Chief Shield R1.kicad_sch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]
